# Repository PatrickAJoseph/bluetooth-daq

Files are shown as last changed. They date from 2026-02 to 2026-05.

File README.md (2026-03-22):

# bluetooth-daq
A simple low-speed Bluetooth enabled DAQ consisting of HV/LV voltage, current measurement, LV analog I/O, resistance measurement, UART, I2C & SPI communication interfaces and a high speed ADC combining multiple functionalities within one device. The device can be operated through a mobile/PC application via Bluetooth or through RS-485 interface. 16 devices can be connected to the RS-485 interface.

## Goal of the product
1. Reduce the number of induvidual electronic test equipment required for electronic hardware/software development.

2. Combine commonly used electronic test functions within a single device

3. Enable versatile interface to the device (RS485, Bluetooth, Web) and test automation support to reduce effort of manual testing.

## Features of the product

### Hardware features

1. 16 low-speed logic level digital inputs (+/ 3.3V) (maximum sampling rate of 100 SPS)
2. 16 low-speed logic level digital outputs (0-3V) with maximum current limit of 5mA / channel (maximum sampling rate of 100 SPS).
3. 2 channel bi-polar differential high-resolution analog inputs (+/-, 50V, 6 digits) with maximum sampling rate of 2 kSPS/channel in single channel sampling mode.
4. 2 channel high speed bipolar differential analog acquisition channels (maximum input signal frequency of 10kHz)
5. 1 UART communication instance (UART_TX, UART_RX) with maximum baud rate of 115200.
6. 1 I2C communication instance (I2C_SDA, I2C_SCL) with maximum clock speed of 400 kHz.
7. 1 SPI communication instance (SPI_MOSI, SPI_MISO, SPI_nCS, SPI_SCLK) with maximum clock speed of 4 MHz.
8. 8 channel differental bi-polar low voltage analog inputs +/- 15V range.
9. 2 current measurement inputs (+/- 50V common mode voltage, and maximum current of 3A).
10. 2 resistance measurement inputs ( 1 ohm to 1 MOhm ).
11. 2 thermistor temperature measurement channels.
12. 8 low speed DC analog outputs.
13. RS-485 interface for remote control.

### Software features

1. RS-485 control of device through PC.
2. Bluetooth control of device from PC/Mobile application.
3. Firmware upgrade through Bluetooth using TI Simplelink Connect app.
4. Simple Web GUI interface for control of device.
5. Python scripting support for remote control of device from PC.
6. LabVIEW support for the device.

## Hardware block diagram

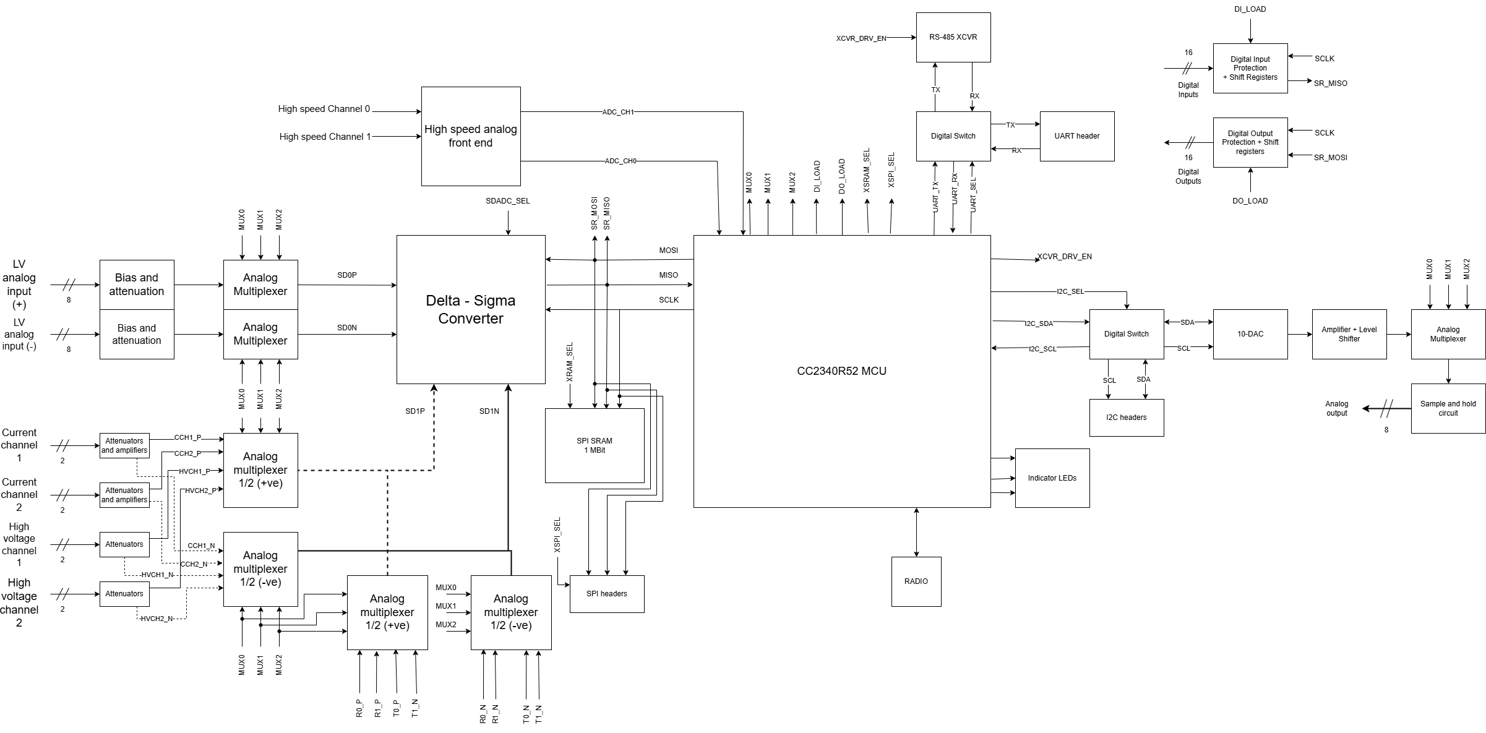
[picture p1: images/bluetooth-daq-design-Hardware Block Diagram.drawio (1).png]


### High voltage analog inputs

The device provides 2 high voltage analog inputs with a range of +/- 50V and maximum input frequency of 200 Hz. The high voltage analog input front end attenuates the input voltage signal and adds bias to meet voltage level requirements of the sigma-delta ADC inputs.

### Current inputs

The device provides 2 current inputs with common mode voltage upto +/- 50V and a range of +/- 3A. The voltage drop across the
current measurement terminal is 0.1V/A.

### Low voltage analog inputs

The device provides 8 channel +/- 15V low voltage analog inputs.
Maximum input frequency per channel is set to 200 Hz.

### Resistance measurement

The device provides 2 channel resistance measurement feature.
The supported resistance measurement range is 1 ohm to 1 MOhm.

### High speed acquisition channels

The device provides 2 single ended high speed analog signal
acquisition channels with sampling frequency of 200 kSPS per
channel, limiting the combined input signal frequency to 10kHz.

### Thermistor temperature measurement channels

The device provides 2 thermistor temperature measurement channels.
The reference voltage for the thermistor interface is 3.3V and reference resistance is 10k. The device comes with a calibration table for a 10K NTC. If user uses any other NTC, then, the calibration table for thermistor has to be manually entered by the user via software.

### Sigma-Delta ADC

The heart of most of the analog to digital conversions is carried out by a 24-bit sigma-delta ADC (ADS131M02: https://www.ti.com/lit/ds/symlink/ads131m02.pdf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).

The input to each channel of the ADC is multiplexed with the help of analog multiplexer (CD4051: https://www.ti.com/lit/ds/symlink/cd4051b.pdf)

### Low speed analog outputs

The device provides 8 analog outputs with range +/- 10V. Since a sample and hold circuit is used at the output stage, the output current limit is 1mA and so an external buffer must be used. The DAC used in the solution is DAC101C081 (https://www.ti.com/product/DAC101C081)

### SPI SRAM

The device uses a 1 MBit SRAM to store samples acquired from various modules such as high speed ADC, digital inputs, digital output patterns etc. The SRAM used is 23LCV1024 (https://ww1.microchip.com/downloads/en/DeviceDoc/25156A.pdf)

### Digital inputs and outputs

The device provides 16 digital inputs and digital outputs. The digital inputs are read by the MCU through a 74HC165 shift register (https://www.ti.com/lit/ds/symlink/sn74hc165.pdf) and the digital outputs are transferred through 74HC595 shift register (https://www.ti.com/lit/ds/symlink/sn74hc595.pdf).

The digital inputs have a range of +/- 3.3V in order to provided reverse voltage protection. The digital outputs have a current limit of 5mA per channel. 

### Indicator LEDs

There are three indicator LEDs, 1 green, 1 red and 1 yellow.
The green LED indicates status of any ongoing communication between host and the device. The red LED indicates any error which has occured in the device. The yello LED indicates that a firmware upgrade is going on the device.

### MCU

The microcontroller used in the device is CC2340R52 (https://www.ti.com/product/CC2340R5/part-details/CC2340R52E0RGER) which is an ARM Cortex-M0+ MCU with 512 KB FLASH and 36 KB RAM.

### UART, I2C and SPI interfaces

The device provides an SPI, I2C and a UART interface which can be used by the user to transfer bytes to external devices under test.

## Software block diagram

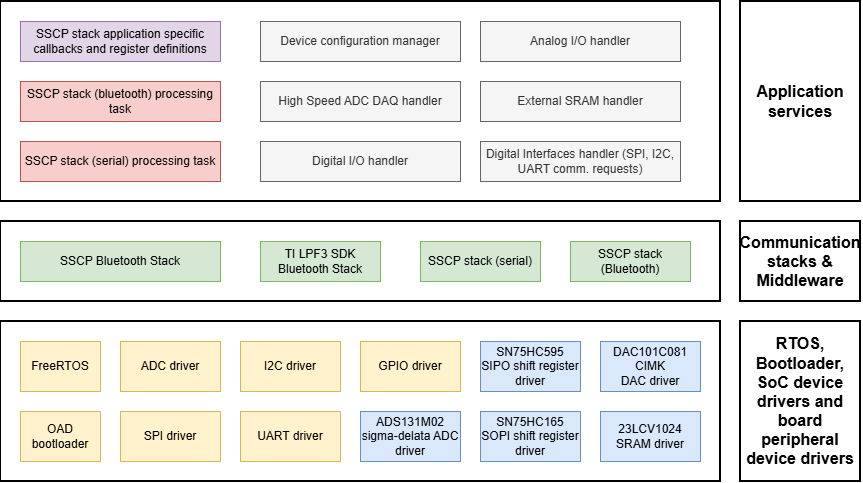
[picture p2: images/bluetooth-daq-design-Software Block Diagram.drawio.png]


### RTOS

The software uses FreeRTOS operating system. This is required by the TI Bluetooth Stack and also for multithreading purposes.

### Soc Peripheral Drivers

The following SoC peripheral drivers are required by the product.

| Driver | Description |
|---|---|
| ADC |  Required by the high speed analog input module  |
| SPI |  Required for accessing the shift registers <br> and the external SRAM memory |
| I2C |  Required to control DAC IC on the board |
| UART |  Required for interaction with host PC through RS-485 interface |
| GPIO | Required by all other drivers |

### Board Peripheral Drivers

| Driver | Purpose |
|---|---|
| ADS131M02 | Controls the 24-bit Sigma-Delta ADC. Performs common operations such as setting ADC PGA gain, calibration, sample acquisition etc. |
| SN75HC595 |  Write data to the digital outputs through shift registers |
| SN75HC165 |  Read data from the SOPI shift registers |
| DAC101C081 |  Required for controlling the external 10-bit for setting the desired output voltage. Also, supports calibration. |
| 23LCV1024 | Controls the external SRAM IC. Provides read and write APIs for the external memory |

### Bootloader and Firmware upgrade

The device supports over the air firmware upgrade through the TI Simplelink Connect application for Mobile (https://www.bing.com/search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). Firmware upgrade over Bluetooth is only supported for mobile phones and not for laptop.

### Bluetooth stack

The device uses the Texas Instruments Bluetooth stack. This stack is required for Bluetooth over the air firmware upgrade and also serves as an interface between the mobile/PC and the device.

### SSCP stack (serial) & SSCP stack (bluetooth)

The SSCP (Simple System Control Protocol) is the transport protocol which is used by the device to interact with the host via serial interface or Bluetooth. Each interface requires a seperate SSCP responder stack instance. For more details about the SSCP protocol refer to the following Git repository: https://github.com/PatrickAJoseph/simple-system-control-protocol.

### SSCP application interface

This software component defines the register callback functions, register definitions related to the application for the SSCP stack.

### SSCP responder stack processing task (serial & Bluetooth)

This software components receives bytes from the interface (serial/Bluetooth) and sends the received byets to the SSCP stack for processing.

### Device configuration manager

Validates the configuration provided by the user. Also, stores and loads device settings in non-volatile storage.

### High speed ADC data acquisition handler

Acquires samples from the high speed acquisition ADC channels and stores conversion results in the external SRAM. Users can then read back the samples stored in the SRAM.

### Digital I/O handler

Used to control the digital inputs and the digital outputs of the device through the shift registers as described in the hardware section. Supports setting, clearing, toggling each DO pin and reading state of DI pins.

### Analog I/O handler

Controls calibration of each high voltage analog input channel, current channel, resistance measurement channel, thermistor temperature measurement channel and analog output channel. Acquires samples from the analog input channels, performs filtering and then adds calibration parameters to provide processed results. Manages the multiplexing of different analog inputs to the input channels of the sigma-delta converter through the multiplexer.

### External SRAM handler

The external SRAM handler is an abstraction component for the external SRAM driver. Responsible for reading and writing data application defined memory regions in the external SRAM memory via the SPI interface.

### Digital interfaces handler (UART, SPI, I2C)

Used to handle received communication interface commands (such as transmit, receive commands) for UART, I2C and SPI protocols. Can handle multiple byte transfer for all interfaces and stores received bytes in the external SRAM for post processing.

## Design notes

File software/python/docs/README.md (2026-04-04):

# Python interface for bluetoth DAQ

The python interface for controlling the bluetooth data acquisition system consists of the following subcomponents:

**Core**: Contains the SSCP protocol core and helper methods to perform basic/common operations.

**Socket**: Implements a socket connection between the DAQ control python script and any other application such as LabVIEW, thereby making interfacing to various applications easier.

**DIO**: The **dio** submodule is used to control the digital inputs/outputs of the DAQ.

**UART**: The **uart** submodule is used to send bytes, receive bytes and transceive bytes via the UART interface of the DAQ.

**SPI**: The **spi** submodule is used to transceive bytes via the SPI inteface of the DAQ.

**I2C**: The **i2c** submodule is used to transceive bytes via the I2C interface of the DAQ.

**hv_analog_in**: The high voltage analog input submodule is used to measure the DC voltage at the high voltage analog inputs of the DAQ.

**lv_analog_in**: The low voltage analog input submodule is used to measure the DC voltage at the low voltage inputs of the DAQ.

**analog_out**: The analog output submodule is used to control the analog outputs of the DAQ.

**current**: The current submodule is used to measure the current flowing through the current measurement inputs of the DAQ.

**resistance**: The resistance submodule is used to measure the resistance across the resistance input terminals of the DAQ.

**temperature**: The temperature submodule is used to measure the resistance of the thermistor connected across the thermistor input terminals of the DAQ and map it to a temperature value based on the resistance-vs-temperature curve provided by the user.

## bdaq

The bluetooth DAQ API is the high level module which abstracts all other submodules. All other submodules are only accessible through this module. This module consists of functions to initialize the bluetooth DAQ, set the communication interface (Serial/BLE) and other utility functions.

### members

>__bdaq.interface__

Defines the type of communication interface used to communicate with the DAQ.

**Permitted values** 

__bdaq.interface.SERIAL__

Select communication interface as serial interface. Device will interact with the host PC via RS-485 interface.

__bdaq.interface.BLE__

Select communication interface as BLE interface. Device will interact with the host PC via BLE.

### methods

>**bdaq**( *interface*: **bdaq.interface**, *id*: **int**, *comm_timeout*: **int**, *serial_number*: **int**)

Initializes the SSCP protocol stack for communicating with the DAQ with the required interface, device ID, communication interface timeout and device serial number. It also puts the device into the default state.

***Parameters***

*interface* : The communcation interface between the DAQ and the host PC. Can be either BLE or SERIAL.

*id* : The device ID of the DAQ. This number is useful for addressing a specific device among a number of devices connected to the same RS485 bus. It can take an integer value from 0 to 15. Passing any other values throws an exception.

*comm_timeout* : The communication timeout period in milli-seconds. If the DAQ does not respond within the specified timeout, a timeout exception is thrown.

*serial_number* : A 10-digit serial number which will be associated a DAQ during production. This number is important when communicating with the device via BLE.

## Core

The **core** submodule abstracts the SSCP (https://github.com/PatrickAJoseph/simple-system-control-protocol/tree/main/source/python) protocol APIs. 

>**bdaq.core**( *interface*: **initiator.InterfaceType**, *id*: **int**, *comm_timeout*: **int**, *port* : **str**, *serial_number*: **int**)

Initializes the SSCP protocol stack for communicating with the DAQ with the required interface, device ID, communication interface timeout and device serial number.

***Parameters***

*interface* : The communcation interface between the DAQ and the host PC. Can be either BLE or SERIAL.

*id* : The device ID of the DAQ. This number is useful for addressing a specific device among a number of devices connected to the same RS485 bus. It can take an integer value from 0 to 15. Passing any other values throws an exception.

*comm_timeout* : The communication timeout period in milli-seconds. If the DAQ does not respond within the specified timeout, a timeout exception is thrown.

*port* : The port identifier of the COM Port / TTY used for serial communication.

*serial_number* : A 10-digit serial number which will be associated a DAQ during production. This number is important when communicating with the device via BLE.

>**bdaq.core.write_parameters**(*names*: **str[]**, *values*: **int[]**)

Writes the list of parameter names with the list of parameter values. This function takes longer time to execute as each parameter will be written to the device.

***Parameters***

*names* : The list of parameter names to be written into the device.

*values* : The list of corresponding parameter values to be written in the device.

>**bdaq.core.write_parameters_last**(*names*: **str[]**, *values*: **int[]**)

Writes the list of parameter names with the list of parameter values. This loads all parameter values into memory and only then initiates a write to device operation. __Make sure that all the parameters mentioned in the list belong to the same device register__ (Refer to `ble-daq.yml` configuration file for more details) 

***Parameters***

*names* : The list of parameter names to be written into the device.

*values* : The list of corresponding parameter values to be written in the device.

>**bdaq.core.read_parameters**(*names* : **str[]**)

Reads the list of parameters from the device and returns a list containing their values

***Parameters***

*names* : The list of parameter names to be read from the device.

## DIO

The **D**igital **I**nput **O**utput module is used to control the digital inputs and digital outputs of the DAQ. This module allows reading and writing states of all pins at once as well as individually.

>**daq.dio.read_input**()

Returns the states of the digital input pins as a 16-bit integer.

>**daq.dio.read_output**()

Returns the states of the digital output pins as a 16-bit integer.

>**daq.dio.write_output**(*output* : **int**)

Writes the 16-bit output word to the digital outputs of the DAQ.

*Parameters*

*output* : The 16-bit output which has to be written to the digital output pins of the DAQ. The value of *output* must range from 0 to 65535. Any other values throws a *ValueError*.

>**bdaq.dio.set_output_pin_state**( *pin* : **int**, *state* : **Bool** )

Sets state of digital output *pin* to the assigned *state*. The *pin* can take values from 0 to 15. Any other values throws *ValueError*.

*Parameters*

*pin* : The pin number of the digital output which has to be controlled. Valid value of *pin* is from 0 to 15.

*state* : The state of the digital output pin.

>**bdaq.dio.get_output_pin_state**( *pin* : **int** )

Gets the state of the output *pin*. Returns __True__ ifoutput state high, else, returns __False__

*Parameters*

*pin* : The pin number in the digital output whose state has to be examined.

>**bdaq.dio.toggle_output_pin_state**( *pin* : **int** )

Toggles the state of the output *pin*.

*Parameters*

*pin* : The pin number in the digital output whose state has to be toggled.

>**bdaq.dio.get_input_pin_state**( *pin* : **int** )

Gets the state of the digital input *pin*. Returns __True__ if input state is high, else, returns __False__

*Parameters*

*pin* : The pin number in the digital input whose state has to be examined.

## UART

The UART submodule provides features to configure the user UART, send data and receive data from an external device. The current implementation supports a data length of only 8 bits.

### Types

>**dio.uart.stop_bits**

Defines the number of supported stop bits. The device only supports 1 and 2 stop bits.

*dio.uart.stop_bits.ONE* : Number of stop bits is 1.

*dio.uart.stop_bits.TWO* : Number of stop bits is 2.

>**dio.uart.parity**

Defines the type of parity for a UART frame.

*dio.uart.parity.NONE* : Parity is set to none.

*dio.uart.parity.EVEN* : Parity is set to even.

*dio.uart.parity.ODD* : Parity is set to odd.

### Methods

>**bdaq.uart.configure**( *baud_rate* : **int**, *stop_bits* : **bdaq.uart.stop_bits**, *parity* : **bdaq.uart.parity** )

Configures the user UART with the specified baud rate, stop bits and parity.

*baud_rate* : The baud rate at which the UART bits have to be transferred. Valid baud rate is from 300 bps to 921600 bps. Values beyond this range will return error.

*stop_bits* : The number of stop bits. The stop bits must be mentioned via the enum.

*parity* : The parity bit settings. This argument must take one of the values from the __bdaq.uart.parity__ enum.

>**bdaq.uart.set_read_timeout**( *timeout* : **int** )

Sets the UART transfer timeout in milliseconds. Required for UART read operations. Timeout value can range from 0 to 60000. Values other than that will throw *ValueError*.

*timeout* : The UART read timeout specified in milli-seconds.

>**bdaq.uart.write**( *data* : **bytearray** )

Sends the bytes in *data* over the UART interface.

*data* : The data bytes to be sent over the UART TX line.

>**bdaq.uart.read**( *size* : **int**, *timeout* : **int** )

Reads the specified number of bytes (i.e.) *size* available in the UART RX line within the mentioned *timeout* period.

*size* : The number of bytes to be read from the UART RX line.

*timeout* : The timeout duration for the read operation along the UART RX line ( in __milliseconds__ )

>**bdaq.uart.read_then_write**( *write_data* : **bytearray**, *read_size* : **int**, *read_timeout* : **int** )

Reads the number of bytes from the UART Rx line within the mentioned timeout duration and when writes the specified bytes to the UART Tx line.

*write_data* : Byte array containing the btyes to be written via the UART Tx line.

*read_size* : The number of bytes to be read from the UART Rx line.

*read_timeout* : The timeout duration for the read operation along the UART Rx line ( in __milliseconds__ ).

>**bdaq.uart.write_then_read**( *write_data* : **bytearray**, *read_size* : **int**, *read_timeout* : **int** )

Writes the mentioned bytes along the UART Tx line and reads the bytes available along the UART Rx line within the specified timeout interval.

*write_data* : Byte array containing the btyes to be written via the UART Tx line.

*read_size* : The number of bytes to be read from the UART Rx line.

*read_timeout* : The timeout duration for the read operation along the UART Rx line ( in __milliseconds__ ).

## SPI

The SPI submodules provides features to configure the SPI controller and transfer bytes. The SPI module only supports MSB first transfers. LSB first transfers are not supported.

### Types

>**bdaq.spi.frame_format**

The SPI transfer frame format.

*bdaq.spi.frame_format.CPOL_0_CPHA_0* : SPI mode 0, Clock polarity is 0 and Clock phase is 0.

*bdaq.spi.frame_format.CPOL_0_CPHA_1* : SPI mode 0, Clock polarity is 0 and Clock phase is 1.

*bdaq.spi.frame_format.CPOL_1_CPHA_0* : SPI mode 0, Clock polarity is 1 and Clock phase is 0.

*bdaq.spi.frame_format.CPOL_1_CPHA_1* : SPI mode 0, Clock polarity is 1 and Clock phase is 1.

### Methods

>**bdaq.spi.configure**( *bit_rate* : **int**, *frame_format* : **bdaq.spi.frame_format** )

*bit_rate* : The frequency at which the data bits have to be trandferred. The *bit_rate* must a multiple of 10k and can range from 100kbps to 2 Mbps. Any other values results in *ValueError*.

*frame_format* : The frame format must take one of the values from __bsaq.spi.frame_format* enum.

>**bdaq.spi.transfer**( *write_data* : **bytearray** )

Sends over the bytes specified in the *write_data* byte array via the MOSI line and returns the read bytes via the MISO line in __bytearray__ format.

## I2C

The I2C submodule supports the I2C read and write operations to an I2C peripheral and configuration of the I2C peripheral. The supported modes are standard and fast mode and 7-bit addressing mode.

### Types

>**bdaq.i2c.mode**

Indicates whether transfer mode is standard or fast mode.

*bdaq.i2c.mode.standard* : Transfers bits at 100 kHz.

*bdaq.i2c.mode.fast* : Transfers bits at 400 kHz.

### Methods

>**bdaq.i2c.configure**( *mode* : **bdaq.i2c.mode**, *address* : **int** )

Configures the I2C controller with the required transfer mode and the target peripheral address.

*Parameters*

*mode* : The transfer mode must take arguments only from the bdaq.i2c.mode enum.

*address* : The supported target addresses are from 0 to 127. Passing any other value returns in a *ValueError*.

>**bdaq.i2c.transfer**( *write_data* : **bytearray**, *read_size* : **int** )

Sends over the bytes specified in the *write_data* byte array via the SDA line and reads *read_size* number of bytes from the peripheral via the SDA line.

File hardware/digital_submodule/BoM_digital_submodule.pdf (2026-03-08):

Component label | Component value | Component name
U1, U2 | | SN74HC595D
U3, U4 | | SN74HC165D
U7, U8 | | CD4053BM
U5 | | 23LCV1024
U6 | | SN75176ADR
R1,R2,R3,R4,R5,R6,R7,R8,R9,R10,R 11,R12,R13,R14,R15,R16,R17,R18, R19,R20,R21,R22,R23,R24,R25,R26 ,R27,R28,R29,R30,R31,R32,R33,R3 4,R35 | 620E, 1/4W | SMD resistor
R200, R26, R17, R41, R42, R43, R57, R27, R49 | 10k, 1/4W | SMD resistor
R48, R51, R53, R55 | 22E, 1/4W | SMD resistor
D36, D37, D38, D39, D35, D34, D33 | | SMAJ5.0CA
R39, R40 | 1k, 1/4W | SMD resistor
R38 | 120E, 1/4W | SMD resistor
R58, R59 | 2.2k, 1/4W | SMD resistor
C1,C2,C3,C4,C5,C6,C7,C8,C9,C10,C 11,C12,C13,C14,C15,C16,C29,C30, C31,C32,C33,C34,C35,C36,C40,C41 ,C42,C43,C44,C45,C46,C47 | 100pF, 50V, ceramic | SMD capacitor
DIP0, DIP1, DIP2, DIP3, DIP4, DIP5,DIP6, DIP7, DIP8, DIP9, DIP10, DIP11, DIP12, DIP13, DIP14, DIP15 | 1A, 40V, SS14, Schottky diode | SS14 / Schottky Diode
C48, C17, C23, C20, C51, C54, C56, C37 | 100nF, 50v, ceramic | SMD capacitor
C49, C18, C24, C21, C52, C55, C57, C36 | 1u, 50V, ceramic | SMD capacitor
C50, C19, C25, C22, C53, C39 | 10u, 50V, ceramic | SMD capacitor

Quantity | Footprint / package / size
4 | SOIC(D) 16
4 | SOIC(D) 16
4 | SOIC(D) 16
2 | SOIC-8
2 | SOIC-8
40 | SMD_0805
20 | SMD_0805
10 | SMD_0805
20 | DO_214AC
10 | SMD_0805
5 | SMD_1206
10 | SMD_0805
40 | SMD_0805
30 | DO_214AC
20 | SMD_0805
20 | SMD_0805
20 | SMD_0805

Purchase link

SN74HC595D Texas Instruments | Integrated Circuits (ICs) | DigiKey (https://www.digikey.com/en/products/detail/texas-instruments/SN74HC595D/376752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)
SN74HC165D Texas Instruments | Integrated Circuits (ICs) | DigiKey
Marketplace (https://www.digikey.com/en/products/detail/texas-instruments/SN74HC165D/376951)
CD4053BM Texas Instruments | Integrated Circuits (ICs) | DigiKey
Marketplace (https://www.digikey.com/en/products/detail/texas-instruments/CD4053BM/1691172)
23LCV1024-I/SN Microchip Technology | Integrated Circuits (ICs) |
DigiKey (https://www.digikey.com/en/products/detail/microchip-technology/23LCV1024-I-SN/3543093)
SN75176ADR Texas Instruments | Integrated Circuits (ICs) | DigiKey (https://www.digikey.in/en/products/detail/texas-instruments/SN75176ADR/562956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)
RC0805JR-07620RL YAGEO | Resistors | DigiKey (https://www.digikey.in/en/products/detail/yageo/RC0805JR-07620RL/728357)
CRCW080510K0JNEA Vishay Dale | Resistors | DigiKey (https://www.digikey.com/en/products/detail/vishay-dale/CRCW080510K0JNEA/1175222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)
CR0805-JW-220ELF Bourns Inc. | Resistors | DigiKey (https://www.digikey.in/en/products/detail/bourns-inc/CR0805-JW-220ELF/3785269)
SMAJ5.0CA Shenzhen Slkormicro Semicon Co., Ltd. | Circuit
Protection | DigiKey (https://www.digikey.in/en/products/detail/shenzhen-slkormicro-semicon-co-ltd/SMAJ5-0CA/25701316)
Generic
Generic
Generic

Generic

SS14 onsemi | Discrete Semiconductor Products | DigiKey (https://www.digikey.com/en/products/detail/onsemi/SS14/965474?msockid=05dadbf74f856ea33b13cf394e376f90)

Generic

Generic
Generic

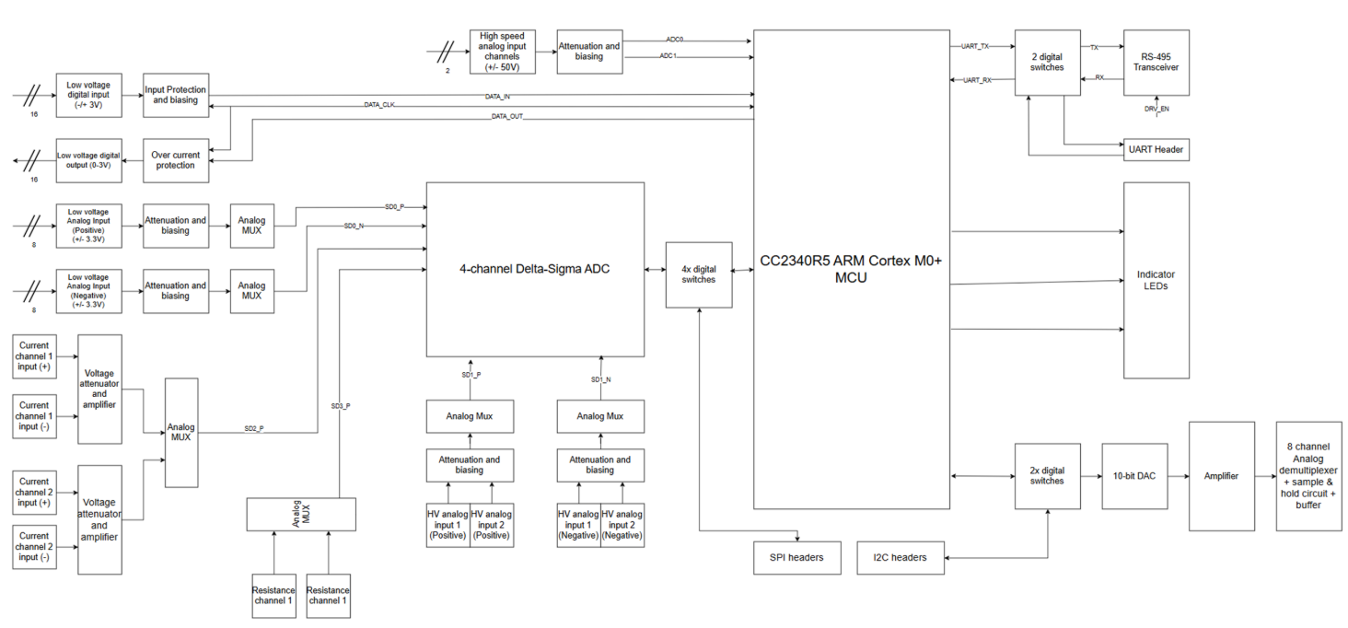
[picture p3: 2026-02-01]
image.png

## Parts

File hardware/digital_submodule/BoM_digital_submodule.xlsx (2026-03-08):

Component label | Component value | Component name | Quantity | Footprint / package / size | Purchase link
U1, U2 |  | SN74HC595D | 4 | SOIC(D) 16 | SN74HC595D Texas Instruments | Integrated Circuits (ICs) | DigiKey (https://www.digikey.com/en/products/detail/texas-instruments/SN74HC595D/376752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)
U3, U4 |  | SN74HC165D | 4 | SOIC(D) 16 | SN74HC165D Texas Instruments | Integrated Circuits (ICs) | DigiKey Marketplace (https://www.digikey.com/en/products/detail/texas-instruments/SN74HC165D/376951)
U7, U8 |  | CD4053BM | 4 | SOIC(D) 16 | CD4053BM Texas Instruments | Integrated Circuits (ICs) | DigiKey Marketplace (https://www.digikey.com/en/products/detail/texas-instruments/CD4053BM/1691172)
U5 |  | 23LCV1024 | 2 | SOIC-8 | 23LCV1024-I/SN Microchip Technology | Integrated Circuits (ICs) | DigiKey (https://www.digikey.com/en/products/detail/microchip-technology/23LCV1024-I-SN/3543093)
U6 |  | SN75176ADR | 2 | SOIC-8 | SN75176ADR Texas Instruments | Integrated Circuits (ICs) | DigiKey (https://www.digikey.in/en/products/detail/texas-instruments/SN75176ADR/562956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)
R1,R2,R3,R4,R5,R6,R7,R8,R9,R10,R11,R12,R13,R14,R15,R16,R17,R18,R19,R20,R21,R22,R23,R24,R25,R26,R27,R28,R29,R30,R31,R32,R33,R34,R35 | 620E, 1/4W | SMD resistor | 40 | SMD_0805 | RC0805JR-07620RL YAGEO | Resistors | DigiKey (https://www.digikey.in/en/products/detail/yageo/RC0805JR-07620RL/728357)
R200, R26, R17, R41, R42, R43, R57, R27, R49 | 10k, 1/4W | SMD resistor | 20 | SMD_0805 | CRCW080510K0JNEA Vishay Dale | Resistors | DigiKey (https://www.digikey.com/en/products/detail/vishay-dale/CRCW080510K0JNEA/1175222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)
R48, R51, R53, R55 | 22E, 1/4W | SMD resistor | 10 | SMD_0805 | CR0805-JW-220ELF Bourns Inc. | Resistors | DigiKey (https://www.digikey.in/en/products/detail/bourns-inc/CR0805-JW-220ELF/3785269)
D36, D37, D38, D39, D35, D34, D33 |  | SMAJ5.0CA | 20 | DO_214AC | SMAJ5.0CA Shenzhen Slkormicro Semicon Co., Ltd. | Circuit Protection | DigiKey (https://www.digikey.in/en/products/detail/shenzhen-slkormicro-semicon-co-ltd/SMAJ5-0CA/25701316)
R39, R40 | 1k, 1/4W | SMD resistor | 10 | SMD_0805 | Generic
R38 | 120E, 1/4W | SMD resistor | 5 | SMD_1206 | Generic
R58, R59 | 2.2k, 1/4W | SMD resistor | 10 | SMD_0805 | Generic
C1,C2,C3,C4,C5,C6,C7,C8,C9,C10,C11,C12,C13,C14,C15,C16,C29,C30,C31,C32,C33,C34,C35,C36,C40,C41,C42,C43,C44,C45,C46,C47 | 100pF, 50V, ceramic | SMD capacitor | 40 | SMD_0805 | Generic
DIP0, DIP1, DIP2, DIP3, DIP4, DIP5,DIP6, DIP7, DIP8, DIP9, DIP10, DIP11, DIP12, DIP13, DIP14, DIP15 | 1A, 40V, SS14, Schottky diode | SS14 / Schottky Diode | 30 | DO_214AC | SS14 onsemi | Discrete Semiconductor Products | DigiKey (https://www.digikey.com/en/products/detail/onsemi/SS14/965474?msockid=05dadbf74f856ea33b13cf394e376f90)
C48, C17, C23, C20, C51, C54, C56, C37 | 100nF, 50v, ceramic | SMD capacitor | 20 | SMD_0805 | Generic
C49, C18, C24, C21, C52, C55, C57, C36 | 1u, 50V, ceramic | SMD capacitor | 20 | SMD_0805 | Generic
C50, C19, C25, C22, C53, C39 | 10u, 50V, ceramic | SMD capacitor | 20 | SMD_0805 | Generic

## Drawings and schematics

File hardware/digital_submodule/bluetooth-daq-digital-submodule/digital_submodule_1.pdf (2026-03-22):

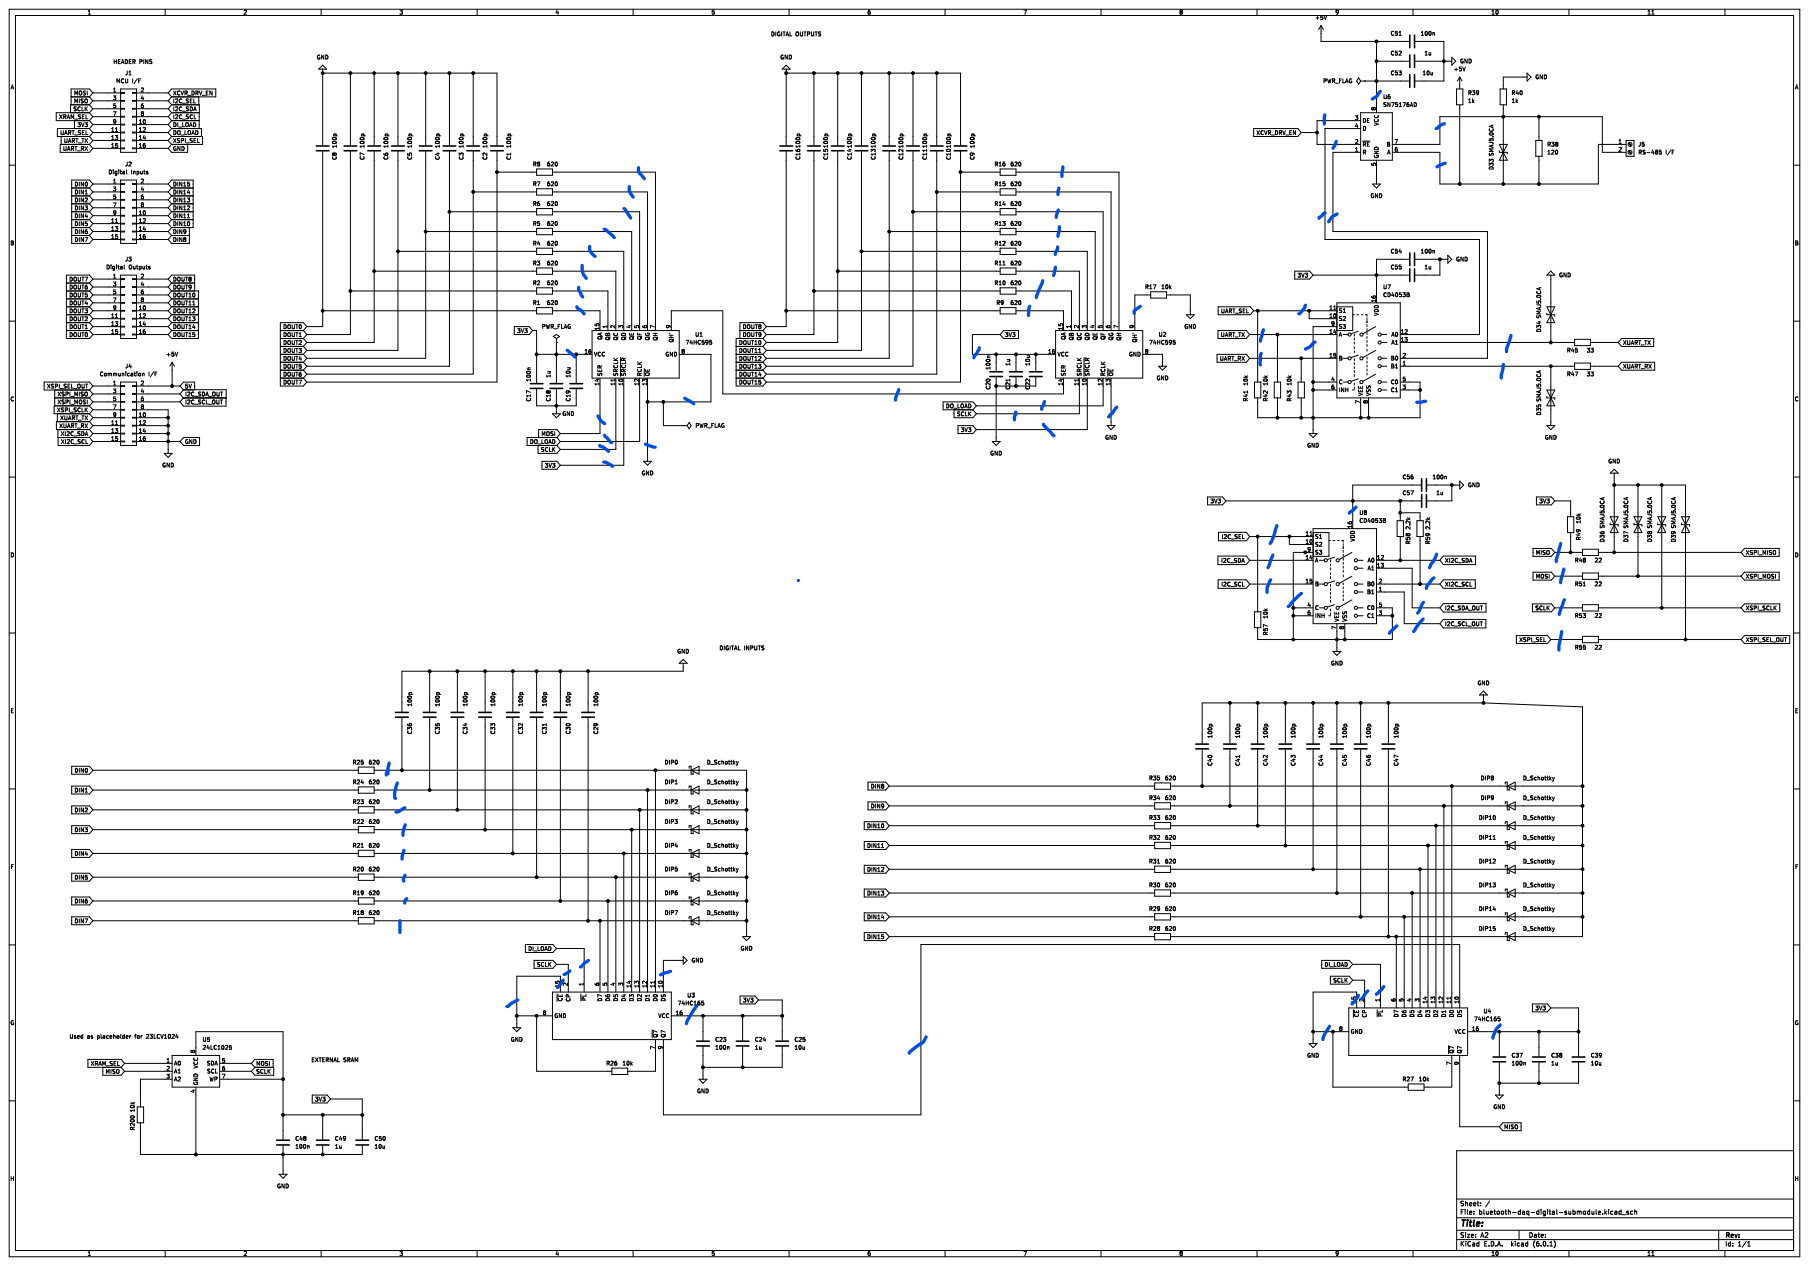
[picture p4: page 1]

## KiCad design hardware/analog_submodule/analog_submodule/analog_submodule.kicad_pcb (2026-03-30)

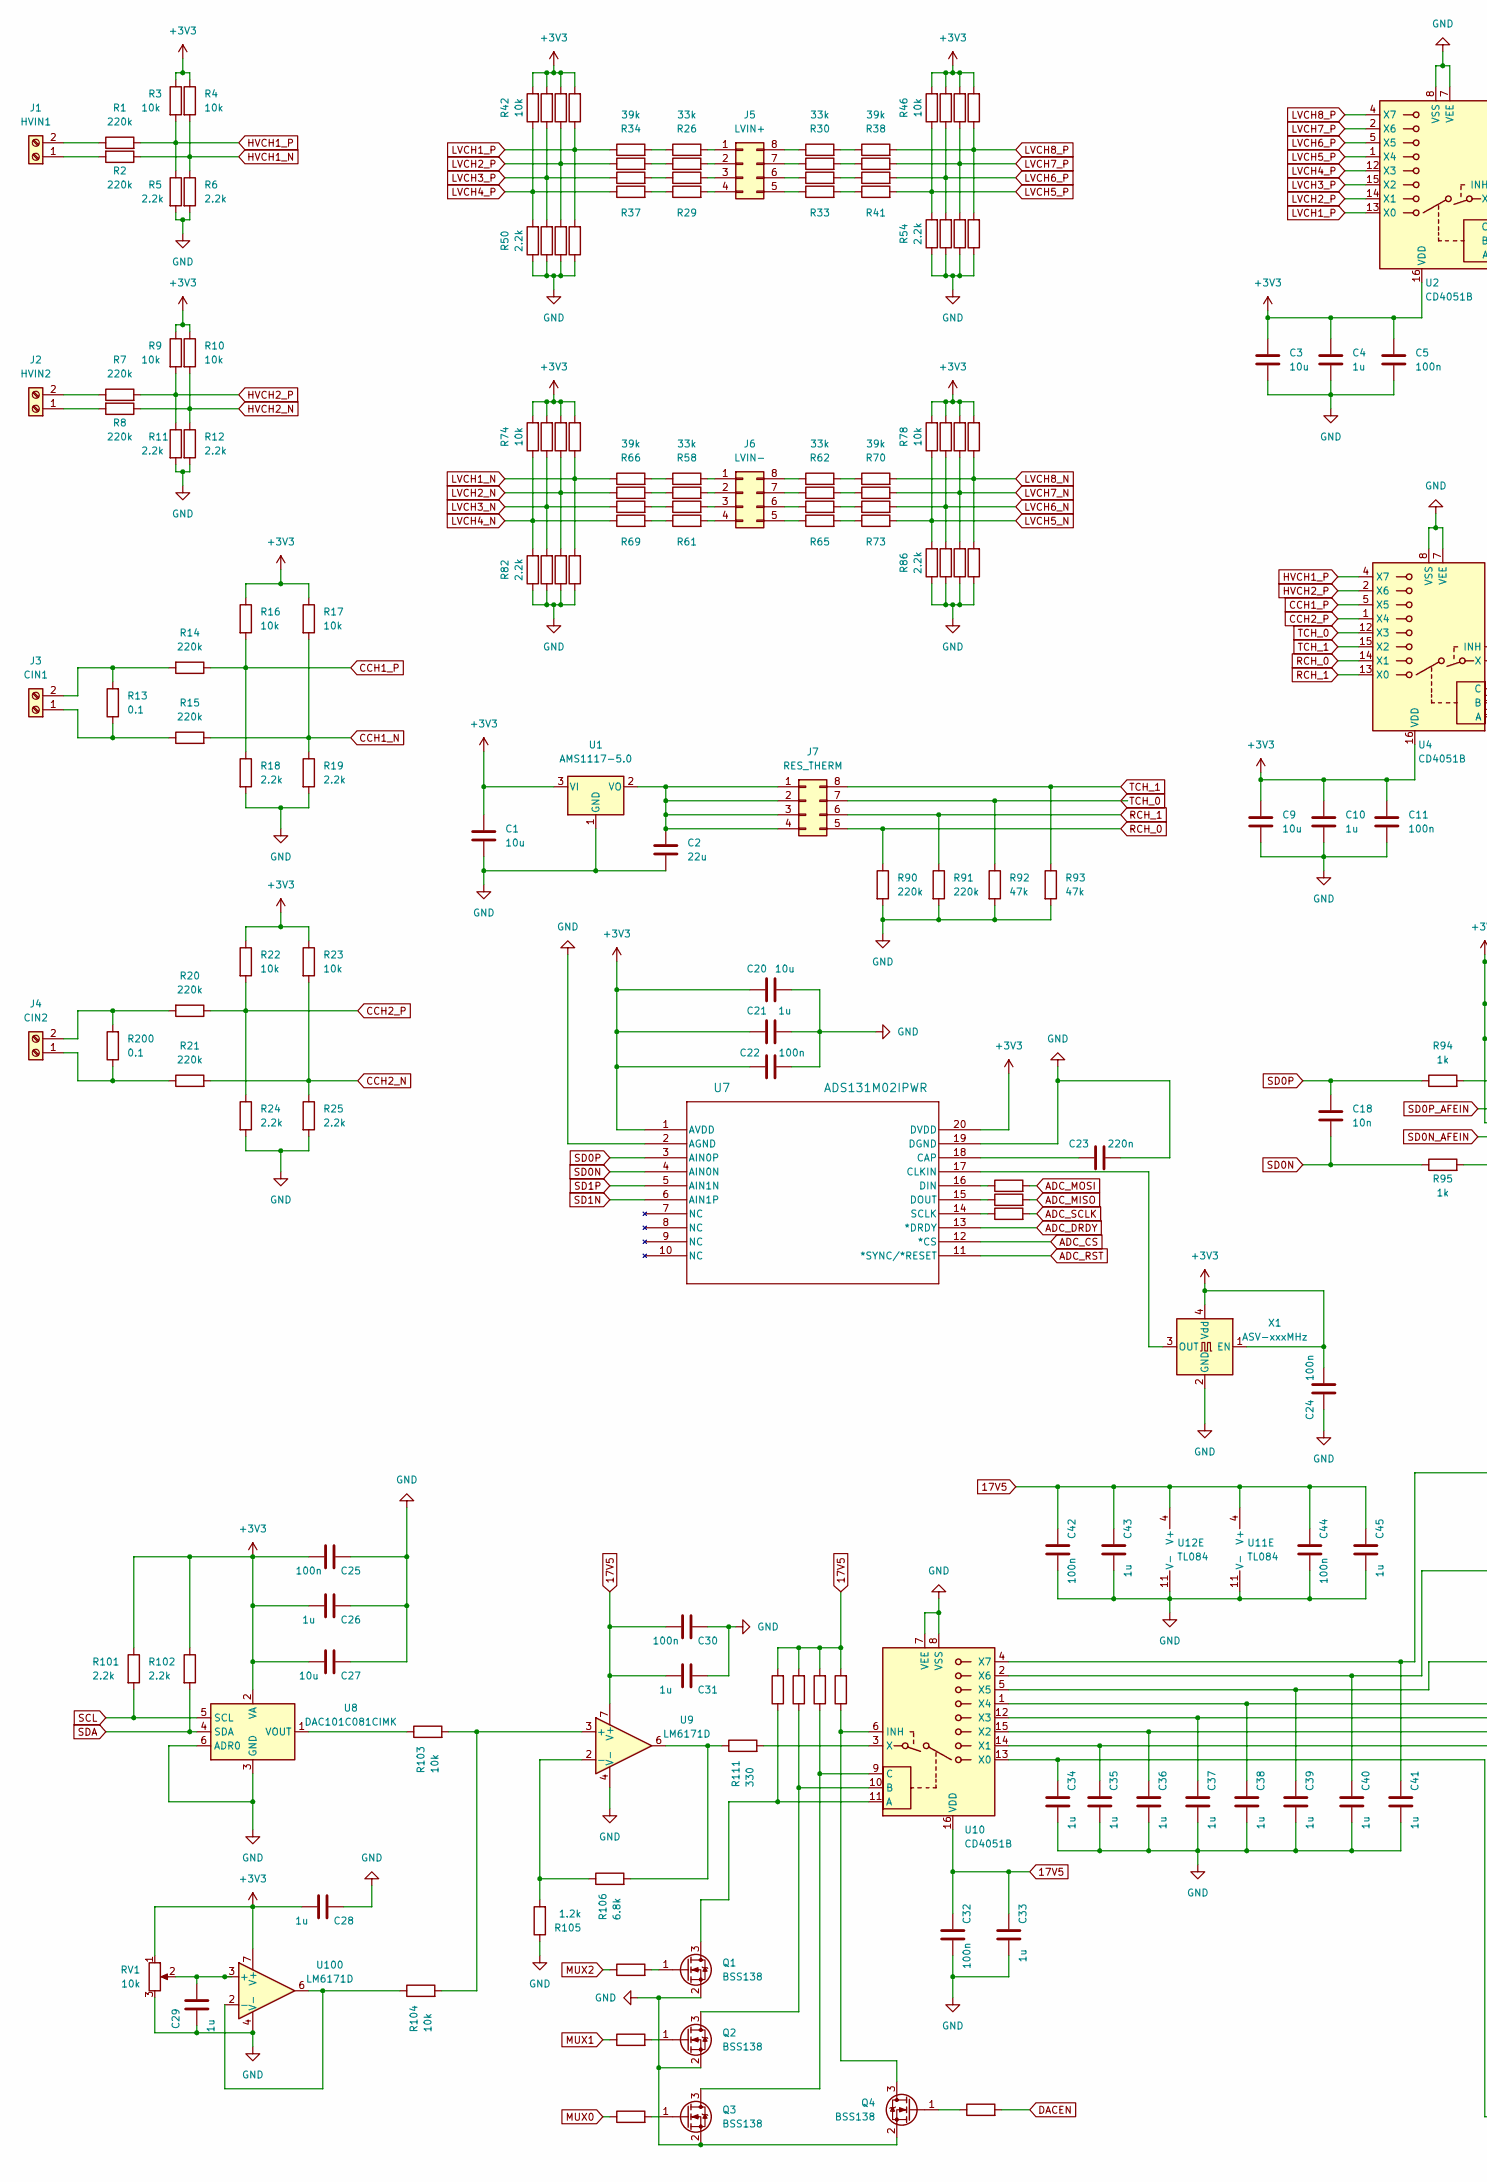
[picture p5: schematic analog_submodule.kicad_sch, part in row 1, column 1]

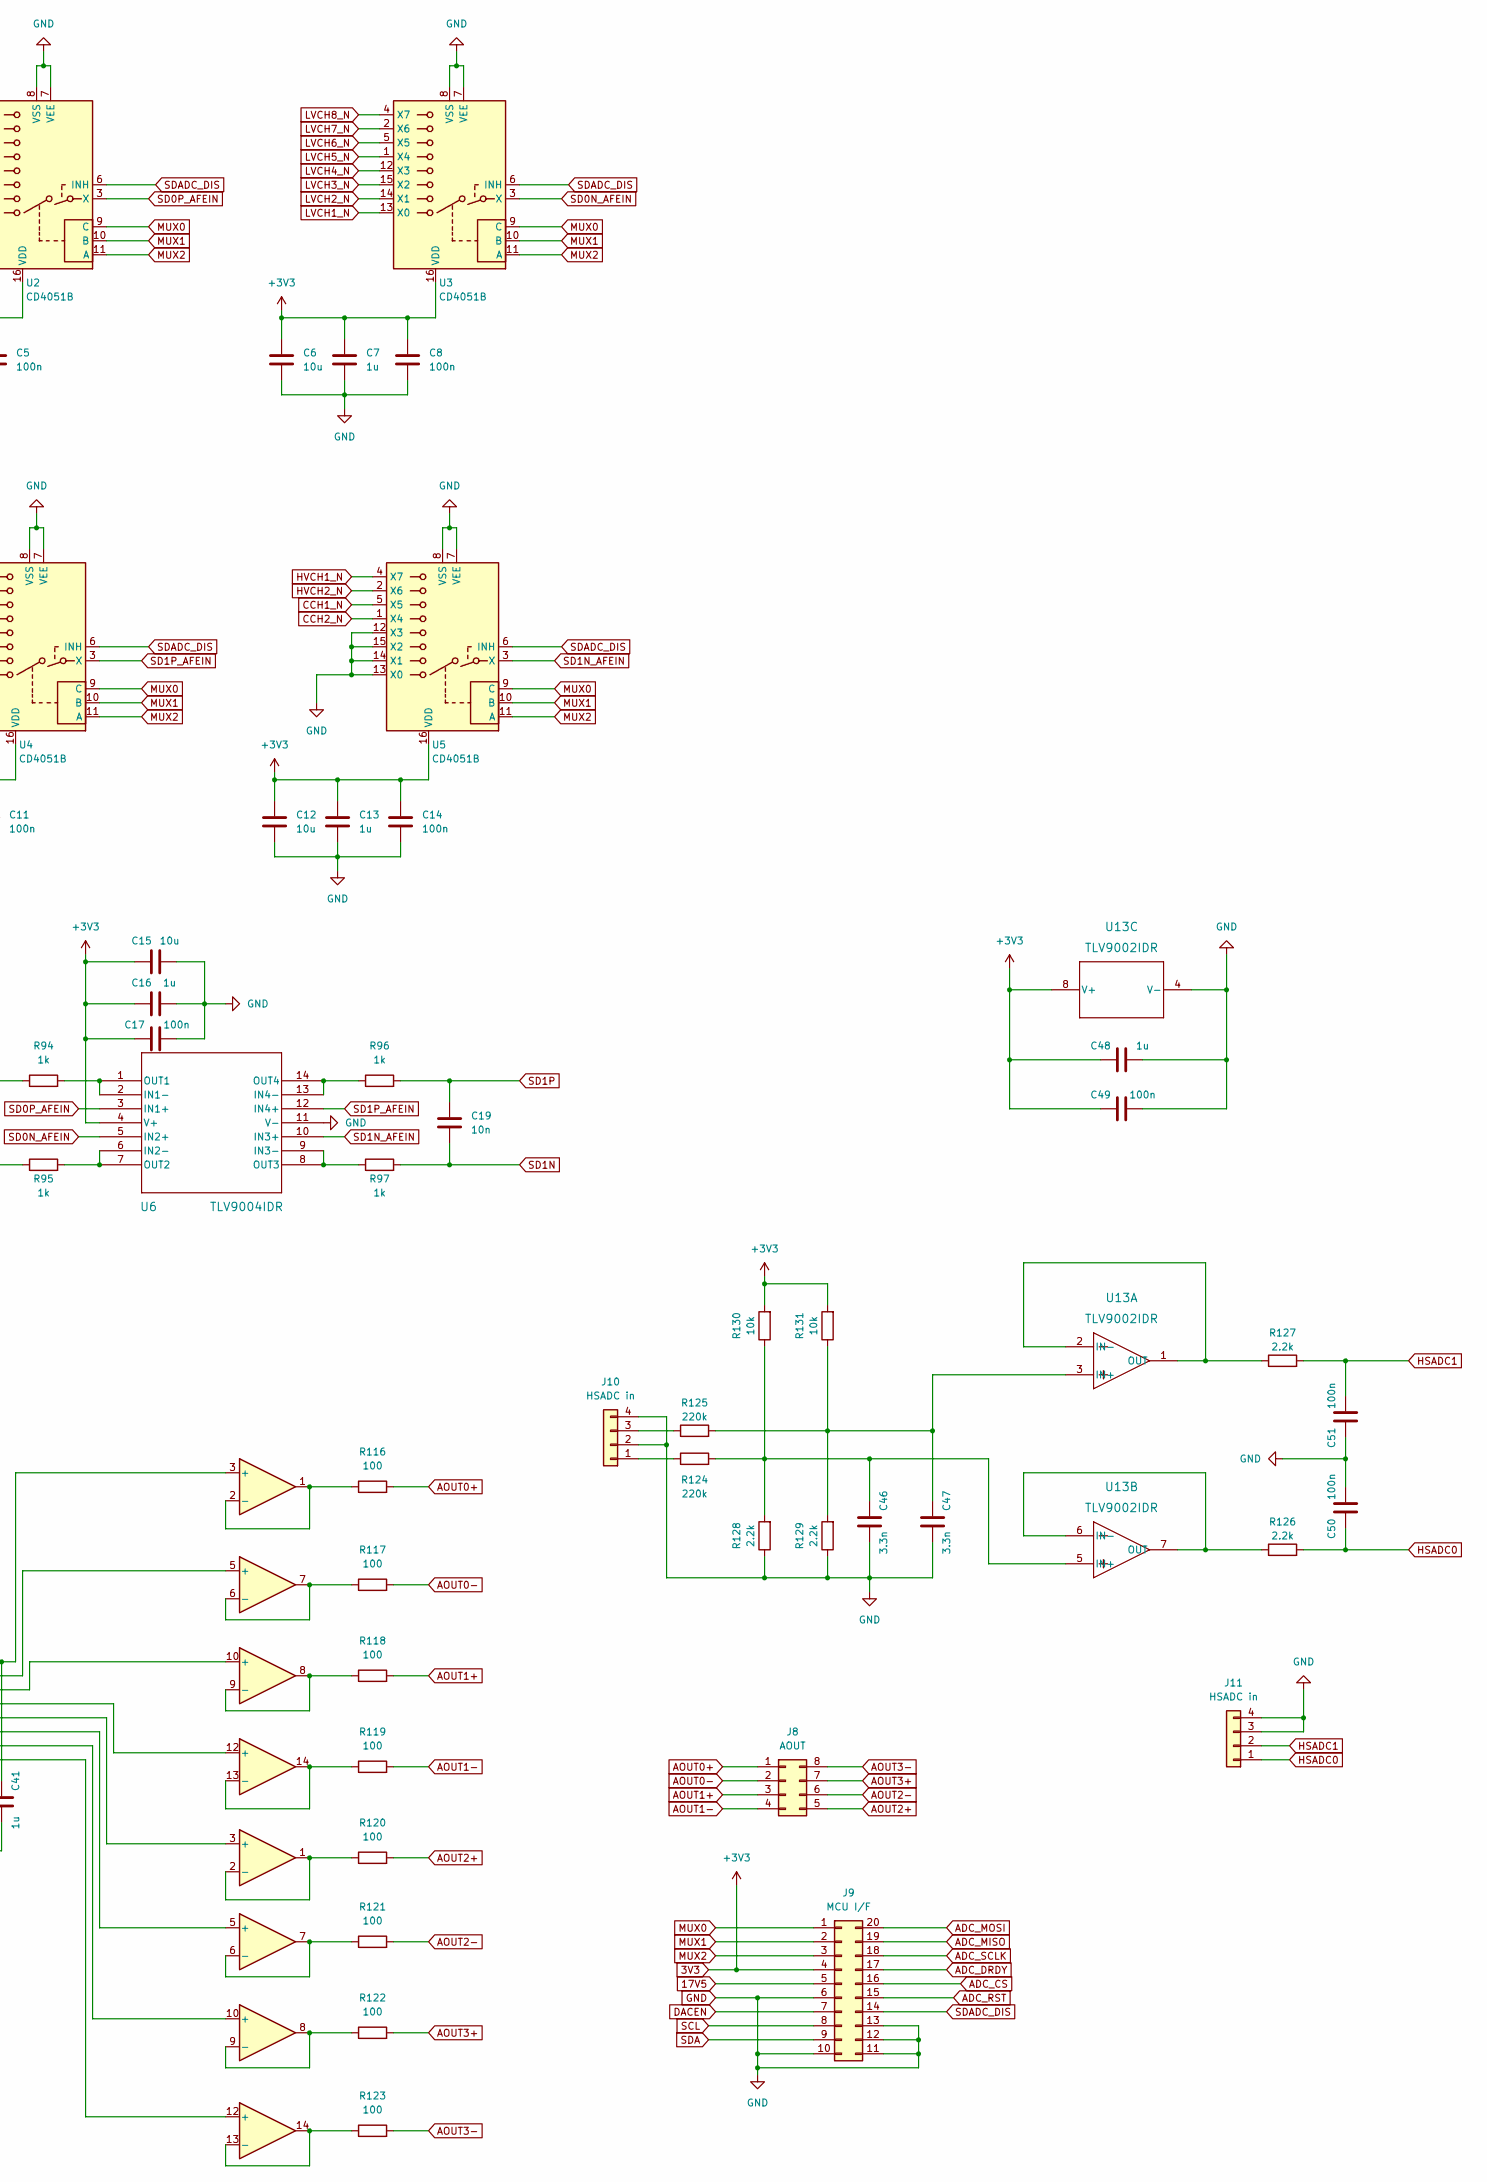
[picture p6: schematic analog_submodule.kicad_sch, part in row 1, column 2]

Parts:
C1, C3, C6, C9, C12, C15, C20, C27: 10u; C_0805_2012Metric_Pad1.18x1.45mm_HandSolder
C2: 22u; C_0805_2012Metric_Pad1.18x1.45mm_HandSolder
C4, C7, C10, C13, C16, C21, C26, C28, C29, C31, C33, C34, C35, C36, C37, C38, C39, C40, C41, C43, C45, C48: 1u; C_0805_2012Metric_Pad1.18x1.45mm_HandSolder
C5, C8, C11, C14, C17, C22, C24, C25, C30, C32, C42, C44, C49, C50, C51: 100n; C_0805_2012Metric_Pad1.18x1.45mm_HandSolder
C18, C19: 10n; C_0805_2012Metric_Pad1.18x1.45mm_HandSolder
C23: 220n; C_0805_2012Metric_Pad1.18x1.45mm_HandSolder
C46, C47: 3.3n; C_0805_2012Metric_Pad1.18x1.45mm_HandSolder
J1: HVIN1; PhoenixContact_MCV_1,5_2-G-5.08_1x02_P5.08mm_Vertical
J2: HVIN2; PhoenixContact_MCV_1,5_2-G-5.08_1x02_P5.08mm_Vertical
J3: CIN1; PhoenixContact_MCV_1,5_2-G-5.08_1x02_P5.08mm_Vertical
J4: CIN2; PhoenixContact_MCV_1,5_2-G-5.08_1x02_P5.08mm_Vertical
J5: LVIN+; PinHeader_2x04_P2.54mm_Vertical
J6: LVIN-; PinHeader_2x04_P2.54mm_Vertical
J7: RES_THERM; PinHeader_2x04_P2.54mm_Vertical
J8: AOUT; PinHeader_2x04_P2.54mm_Vertical
J9: MCU I/F; PinHeader_2x10_P2.54mm_Vertical
J10, J11: HSADC in; PinHeader_1x04_P2.54mm_Vertical
Q1, Q2, Q3, Q4: BSS138; SOT-23
R1, R2, R7, R8, R14, R15, R20, R21, R90, R91, R124, R125: 220k; R_0805_2012Metric_Pad1.20x1.40mm_HandSolder
R3, R4, R9, R10, R16, R17, R22, R23, R42, R43, R44, R45, R46, R47, R48, R49, R74, R75, R76, R77, R78, R79, R80, R81, R103, R104, R107, R108, R109, R110, R130, R131: 10k; R_0805_2012Metric_Pad1.20x1.40mm_HandSolder
R5, R6, R11, R12, R18, R19, R24, R25, R50, R51, R52, R53, R54, R55, R56, R57, R82, R83, R84, R85, R86, R87, R88, R89, R101, R102, R126, R127, R128, R129: 2.2k; R_0805_2012Metric_Pad1.20x1.40mm_HandSolder
R13, R200: 0.1; R_2512_6332Metric_Pad1.40x3.35mm_HandSolder
R26, R27, R28, R29, R30, R31, R32, R33, R58, R59, R60, R61, R62, R63, R64, R65: 33k; R_0805_2012Metric_Pad1.20x1.40mm_HandSolder
R34, R35, R36, R37, R38, R39, R40, R41, R66, R67, R68, R69, R70, R71, R72, R73: 39k; R_0805_2012Metric_Pad1.20x1.40mm_HandSolder
R92, R93: 47k; R_0805_2012Metric_Pad1.20x1.40mm_HandSolder
R94, R95, R96, R97, R112, R113, R114, R115: 1k; R_0805_2012Metric_Pad1.20x1.40mm_HandSolder
R98, R99, R100: 22; R_0805_2012Metric_Pad1.20x1.40mm_HandSolder
R105: 1.2k; R_0805_2012Metric_Pad1.20x1.40mm_HandSolder
R106: 6.8k; R_0805_2012Metric_Pad1.20x1.40mm_HandSolder
R111: 330; R_0805_2012Metric_Pad1.20x1.40mm_HandSolder
R116, R117, R118, R119, R120, R121, R122, R123: 100; R_0805_2012Metric_Pad1.20x1.40mm_HandSolder
RV1: 10k; Potentiometer_Bourns_3266Y_Vertical
U1: AMS1117-5.0; SOT-223-3_TabPin2
U2, U3, U4, U5, U10: CD4051B; D16
U6: TLV9004IDR; SOIC-14_3.9x8.7mm_P1.27mm
U7: ADS131M02IPWR; TSSOP-20_4.4x6.5mm_P0.65mm
U8: DAC101C081CIMK; SOT-23-6
U9, U100: LM6171D; SOIC-8_3.9x4.9mm_P1.27mm
U11, U12: TL084; SOIC-14_3.9x8.7mm_P1.27mm
U13: TLV9002IDR; SOIC-8_3.9x4.9mm_P1.27mm
X1: ASV-xxxMHz; Oscillator_SMD_Abracon_ASV-4Pin_7.0x5.1mm

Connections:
3V3: C1.1, C3.1, C4.1, C5.1, C6.1, C7.1, C8.1, C9.1, C10.1, C11.1, C12.1, C13.1, C14.1, C15.1, C16.1, C17.1, C20.1, C21.1, C22.1, C24.2, C25.2, C26.2, C27.2, C28.2, C48.1, C49.1, J9.4, R3.1, R4.1, R9.1, R10.1, R16.1, R17.1, R22.1, R23.1, R42.2, R43.2, R44.2, R45.2, R46.2, R47.2, R48.2, R49.2, R74.2, R75.2, R76.2, R77.2, R78.2, R79.2, R80.2, R81.2, R101.1, R102.1, R130.2, R131.2, RV1.1, U1.3 (VI), U2.16 (VDD), U3.16 (VDD), U4.16 (VDD), U5.16 (VDD), U6.4 (V+), U7.1 (AVDD), U7.20 (DVDD), U8.2 (VA), U13.8 (V+), U100.7 (V+), X1.1 (EN), X1.4 (Vdd)
17V5: C30.2, C31.2, C32.1, C33.1, C42.1, C43.1, C44.1, C45.1, J9.5, R107.2, R108.2, R109.2, R110.2, U9.7 (V+), U10.16 (VDD), U11.4 (V+), U12.4 (V+)
ADC_CS: J9.16, U7.12 (*CS)
ADC_DRDY: J9.17, U7.13 (*DRDY)
ADC_MISO: J9.19, R99.2
ADC_MOSI: J9.20, R98.2
ADC_RST: J9.15, U7.11 (*SYNC/*RESET)
ADC_SCLK: J9.18, R100.2
AOUT0+: J8.1, R116.2
AOUT0-: J8.2, R117.2
AOUT1+: J8.3, R118.2
AOUT1-: J8.4, R119.2
AOUT2+: J8.5, R120.2
AOUT2-: J8.6, R121.2
AOUT3+: J8.7, R122.2
AOUT3-: J8.8, R123.2
CCH1_N: R15.2, R17.2, R19.1, U5.5 (X5)
CCH1_P: R14.1, R16.2, R18.1, U4.5 (X5)
CCH2_N: R21.2, R23.2, R25.1, U5.1 (X4)
CCH2_P: R20.1, R22.2, R24.1, U4.1 (X4)
DACEN: J9.7, R115.2
GND: C1.2, C2.2, C3.2, C4.2, C5.2, C6.2, C7.2, C8.2, C9.2, C10.2, C11.2, C12.2, C13.2, C14.2, C15.2, C16.2, C17.2, C20.2, C21.2, C22.2, C23.2, C24.1, C25.1, C26.1, C27.1, C28.1, C29.2, C30.1, C31.1, C32.2, C33.2, C34.2, C35.2, C36.2, C37.2, C38.2, C39.2, C40.2, C41.2, C42.2, C43.2, C44.2, C45.2, C46.2, C47.2, C48.2, C49.2, C50.2, C51.1, J9.6, J9.10, J9.11, J9.12, J9.13, J10.2, J10.4, J11.3, J11.4, Q1.2 (S), Q2.2 (S), Q3.2 (S), Q4.2 (S), R5.2, R6.2, R11.2, R12.2, R18.2, R19.2, R24.2, R25.2, R50.1, R51.1, R52.1, R53.1, R54.1, R55.1, R56.1, R57.1, R82.1, R83.1, R84.1, R85.1, R86.1, R87.1, R88.1, R89.1, R90.2, R91.2, R92.2, R93.2, R105.1, R128.1, R129.1, RV1.3, U1.1 (GND), U2.7 (VEE), U2.8 (VSS), U3.7 (VEE), U3.8 (VSS), U4.7 (VEE), U4.8 (VSS), U5.7 (VEE), U5.8 (VSS), U5.12 (X3), U5.13 (X0), U5.14 (X1), U5.15 (X2), U6.11 (V-), U7.2 (AGND), U7.19 (DGND), U8.3 (GND), U8.6 (ADR0), U9.4 (V-), U10.7 (VEE), U10.8 (VSS), U11.11 (V-), U12.11 (V-), U13.4 (V-), U100.4 (V-), X1.2 (GND)
HSADC0: C50.1, J11.1, R126.2
HSADC1: C51.2, J11.2, R127.2
HVCH1_N: R2.1, R4.2, R6.1, U5.4 (X7)
HVCH1_P: R1.2, R3.2, R5.1, U4.4 (X7)
HVCH2_N: R8.1, R10.2, R12.1, U5.2 (X6)
HVCH2_P: R7.2, R9.2, R11.1, U4.2 (X6)
LVCH1_N: R66.1, R77.1, R85.2, U3.13 (X0)
LVCH1_P: R34.1, R45.1, R53.2, U2.13 (X0)
LVCH2_N: R67.1, R76.1, R84.2, U3.14 (X1)
LVCH2_P: R35.1, R44.1, R52.2, U2.14 (X1)
LVCH3_N: R68.1, R75.1, R83.2, U3.15 (X2)
LVCH3_P: R36.1, R43.1, R51.2, U2.15 (X2)
LVCH4_N: R69.1, R74.1, R82.2, U3.12 (X3)
LVCH4_P: R37.1, R42.1, R50.2, U2.12 (X3)
LVCH5_N: R73.2, R78.1, R86.2, U3.1 (X4)
LVCH5_P: R41.2, R46.1, R54.2, U2.1 (X4)
LVCH6_N: R72.2, R79.1, R87.2, U3.5 (X5)
LVCH6_P: R40.2, R47.1, R55.2, U2.5 (X5)
LVCH7_N: R71.2, R80.1, R88.2, U3.2 (X6)
LVCH7_P: R39.2, R48.1, R56.2, U2.2 (X6)
LVCH8_N: R70.2, R81.1, R89.2, U3.4 (X7)
LVCH8_P: R38.2, R49.1, R57.2, U2.4 (X7)
MUX0: J9.1, R114.1, U2.9 (C), U3.9 (C), U4.9 (C), U5.9 (C)
MUX1: J9.2, R113.1, U2.10 (B), U3.10 (B), U4.10 (B), U5.10 (B)
MUX2: J9.3, R112.1, U2.11 (A), U3.11 (A), U4.11 (A), U5.11 (A)
unnamed: C2.1, J7.1, J7.2, J7.3, J7.4, U1.2 (VO)
unnamed: C23.1, U7.18 (CAP)
unnamed: C29.1, RV1.2, U100.3 (+)
unnamed: C34.1, U10.13 (X0), U12.12 (+)
unnamed: C35.1, U10.14 (X1), U12.10 (+)
unnamed: C36.1, U10.15 (X2), U12.5 (+)
unnamed: C37.1, U10.12 (X3), U12.3 (+)
unnamed: C38.1, U10.1 (X4), U11.12 (+)
unnamed: C39.1, U10.5 (X5), U11.10 (+)
unnamed: C40.1, U10.2 (X6), U11.5 (+)
unnamed: C41.1, U10.4 (X7), U11.3 (+)
unnamed: C46.1, R124.2, R128.2, R130.1, U13.5 (IN+)
unnamed: C47.1, R125.2, R129.2, R131.1, U13.3 (IN+)
unnamed: J1.1, R2.2
unnamed: J1.2, R1.1
unnamed: J2.1, R8.2
unnamed: J2.2, R7.1
unnamed: J3.1, R13.1, R15.1
unnamed: J3.2, R13.2, R14.2
unnamed: J4.1, R21.1, R200.1
unnamed: J4.2, R20.2, R200.2
unnamed: J5.1, R26.2
unnamed: J5.2, R27.2
unnamed: J5.3, R28.2
unnamed: J5.4, R29.2
unnamed: J5.5, R33.1
unnamed: J5.6, R32.1
unnamed: J5.7, R31.1
unnamed: J5.8, R30.1
unnamed: J6.1, R58.2
unnamed: J6.2, R59.2
unnamed: J6.3, R60.2
unnamed: J6.4, R61.2
unnamed: J6.5, R65.1
unnamed: J6.6, R64.1
unnamed: J6.7, R63.1
unnamed: J6.8, R62.1
unnamed: J10.1, R124.1
unnamed: J10.3, R125.1
unnamed: Q1.1 (G), R112.2
unnamed: Q1.3 (D), R107.1, U10.11 (A)
unnamed: Q2.1 (G), R113.2
unnamed: Q2.3 (D), R108.1, U10.10 (B)
unnamed: Q3.1 (G), R114.2
unnamed: Q3.3 (D), R109.1, U10.9 (C)
unnamed: Q4.1 (G), R115.1
unnamed: Q4.3 (D), R110.1, U10.6 (INH)
unnamed: R26.1, R34.2
unnamed: R27.1, R35.2
unnamed: R28.1, R36.2
unnamed: R29.1, R37.2
unnamed: R30.2, R38.1
unnamed: R31.2, R39.1
unnamed: R32.2, R40.1
unnamed: R33.2, R41.1
unnamed: R58.1, R66.2
unnamed: R59.1, R67.2
unnamed: R60.1, R68.2
unnamed: R61.1, R69.2
unnamed: R62.2, R70.1
unnamed: R63.2, R71.1
unnamed: R64.2, R72.1
unnamed: R65.2, R73.1
unnamed: R94.2, U6.1 (OUT1), U6.2 (IN1-)
unnamed: R95.2, U6.6 (IN2-), U6.7 (OUT2)
unnamed: R96.1, U6.13 (IN4-), U6.14 (OUT4)
unnamed: R97.1, U6.8 (OUT3), U6.9 (IN3-)
unnamed: R98.1, U7.16 (DIN)
unnamed: R99.1, U7.15 (DOUT)
unnamed: R100.1, U7.14 (SCLK)
unnamed: R103.1, U8.1 (VOUT)
unnamed: R103.2, R104.2, U9.3 (+)
unnamed: R104.1, U100.2 (-), U100.6
unnamed: R105.2, R106.1, U9.2 (-)
unnamed: R106.2, R111.1, U9.6
unnamed: R111.2, U10.3 (X)
unnamed: R116.1, U11.1, U11.2 (-)
unnamed: R117.1, U11.6 (-), U11.7
unnamed: R118.1, U11.8, U11.9 (-)
unnamed: R119.1, U11.13 (-), U11.14
unnamed: R120.1, U12.1, U12.2 (-)
unnamed: R121.1, U12.6 (-), U12.7
unnamed: R122.1, U12.8, U12.9 (-)
unnamed: R123.1, U12.13 (-), U12.14
unnamed: R126.1, U13.6 (IN-), U13.7 (OUT)
unnamed: R127.1, U13.1 (OUT), U13.2 (IN-)
unnamed: U7.17 (CLKIN), X1.3 (OUT)
RCH_0: J7.5, R90.1, U4.14 (X1)
RCH_1: J7.6, R91.1, U4.13 (X0)
SCL: J9.8, R101.2, U8.5 (SCL)
SD0N: C18.2, R95.1, U7.4 (AIN0N)
SD0N_AFEIN: U3.3 (X), U6.5 (IN2+)
SD0P: C18.1, R94.1, U7.3 (AIN0P)
SD0P_AFEIN: U2.3 (X), U6.3 (IN1+)
SD1N: C19.2, R97.2, U7.6 (AIN1P)
SD1N_AFEIN: U5.3 (X), U6.10 (IN3+)
SD1P: C19.1, R96.2, U7.5 (AIN1N)
SD1P_AFEIN: U4.3 (X), U6.12 (IN4+)
SDA: J9.9, R102.2, U8.4 (SDA)
SDADC_DIS: J9.14, U2.6 (INH), U3.6 (INH), U4.6 (INH), U5.6 (INH)
TCH_0: J7.7, R92.1, U4.12 (X3)
TCH_1: J7.8, R93.1, U4.15 (X2)

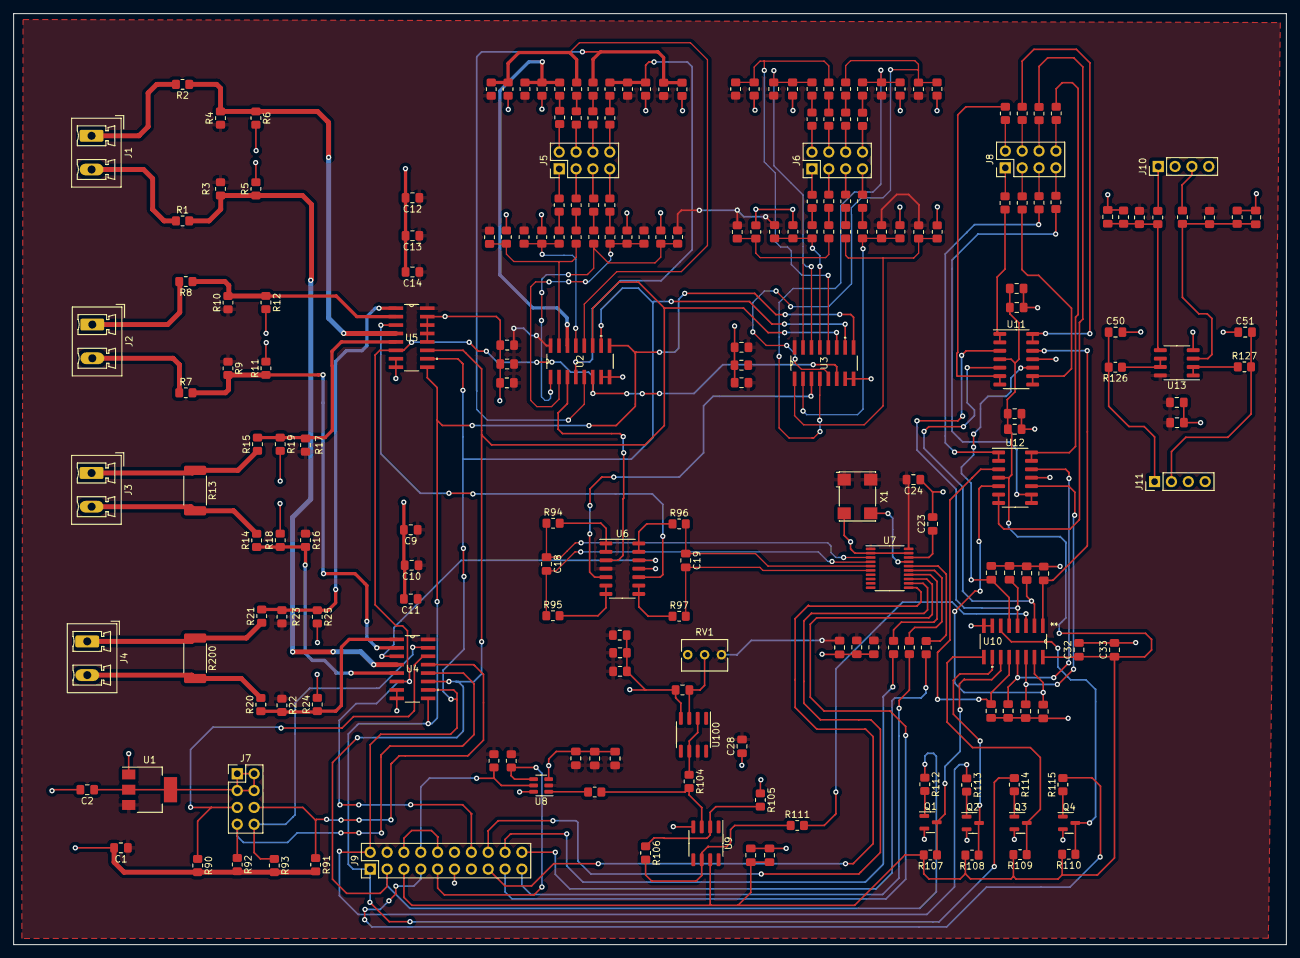
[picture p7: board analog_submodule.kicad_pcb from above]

Board: 2 copper layers, 191.8 x 140.3 mm, 214 parts (0 on the bottom side), 149 nets.

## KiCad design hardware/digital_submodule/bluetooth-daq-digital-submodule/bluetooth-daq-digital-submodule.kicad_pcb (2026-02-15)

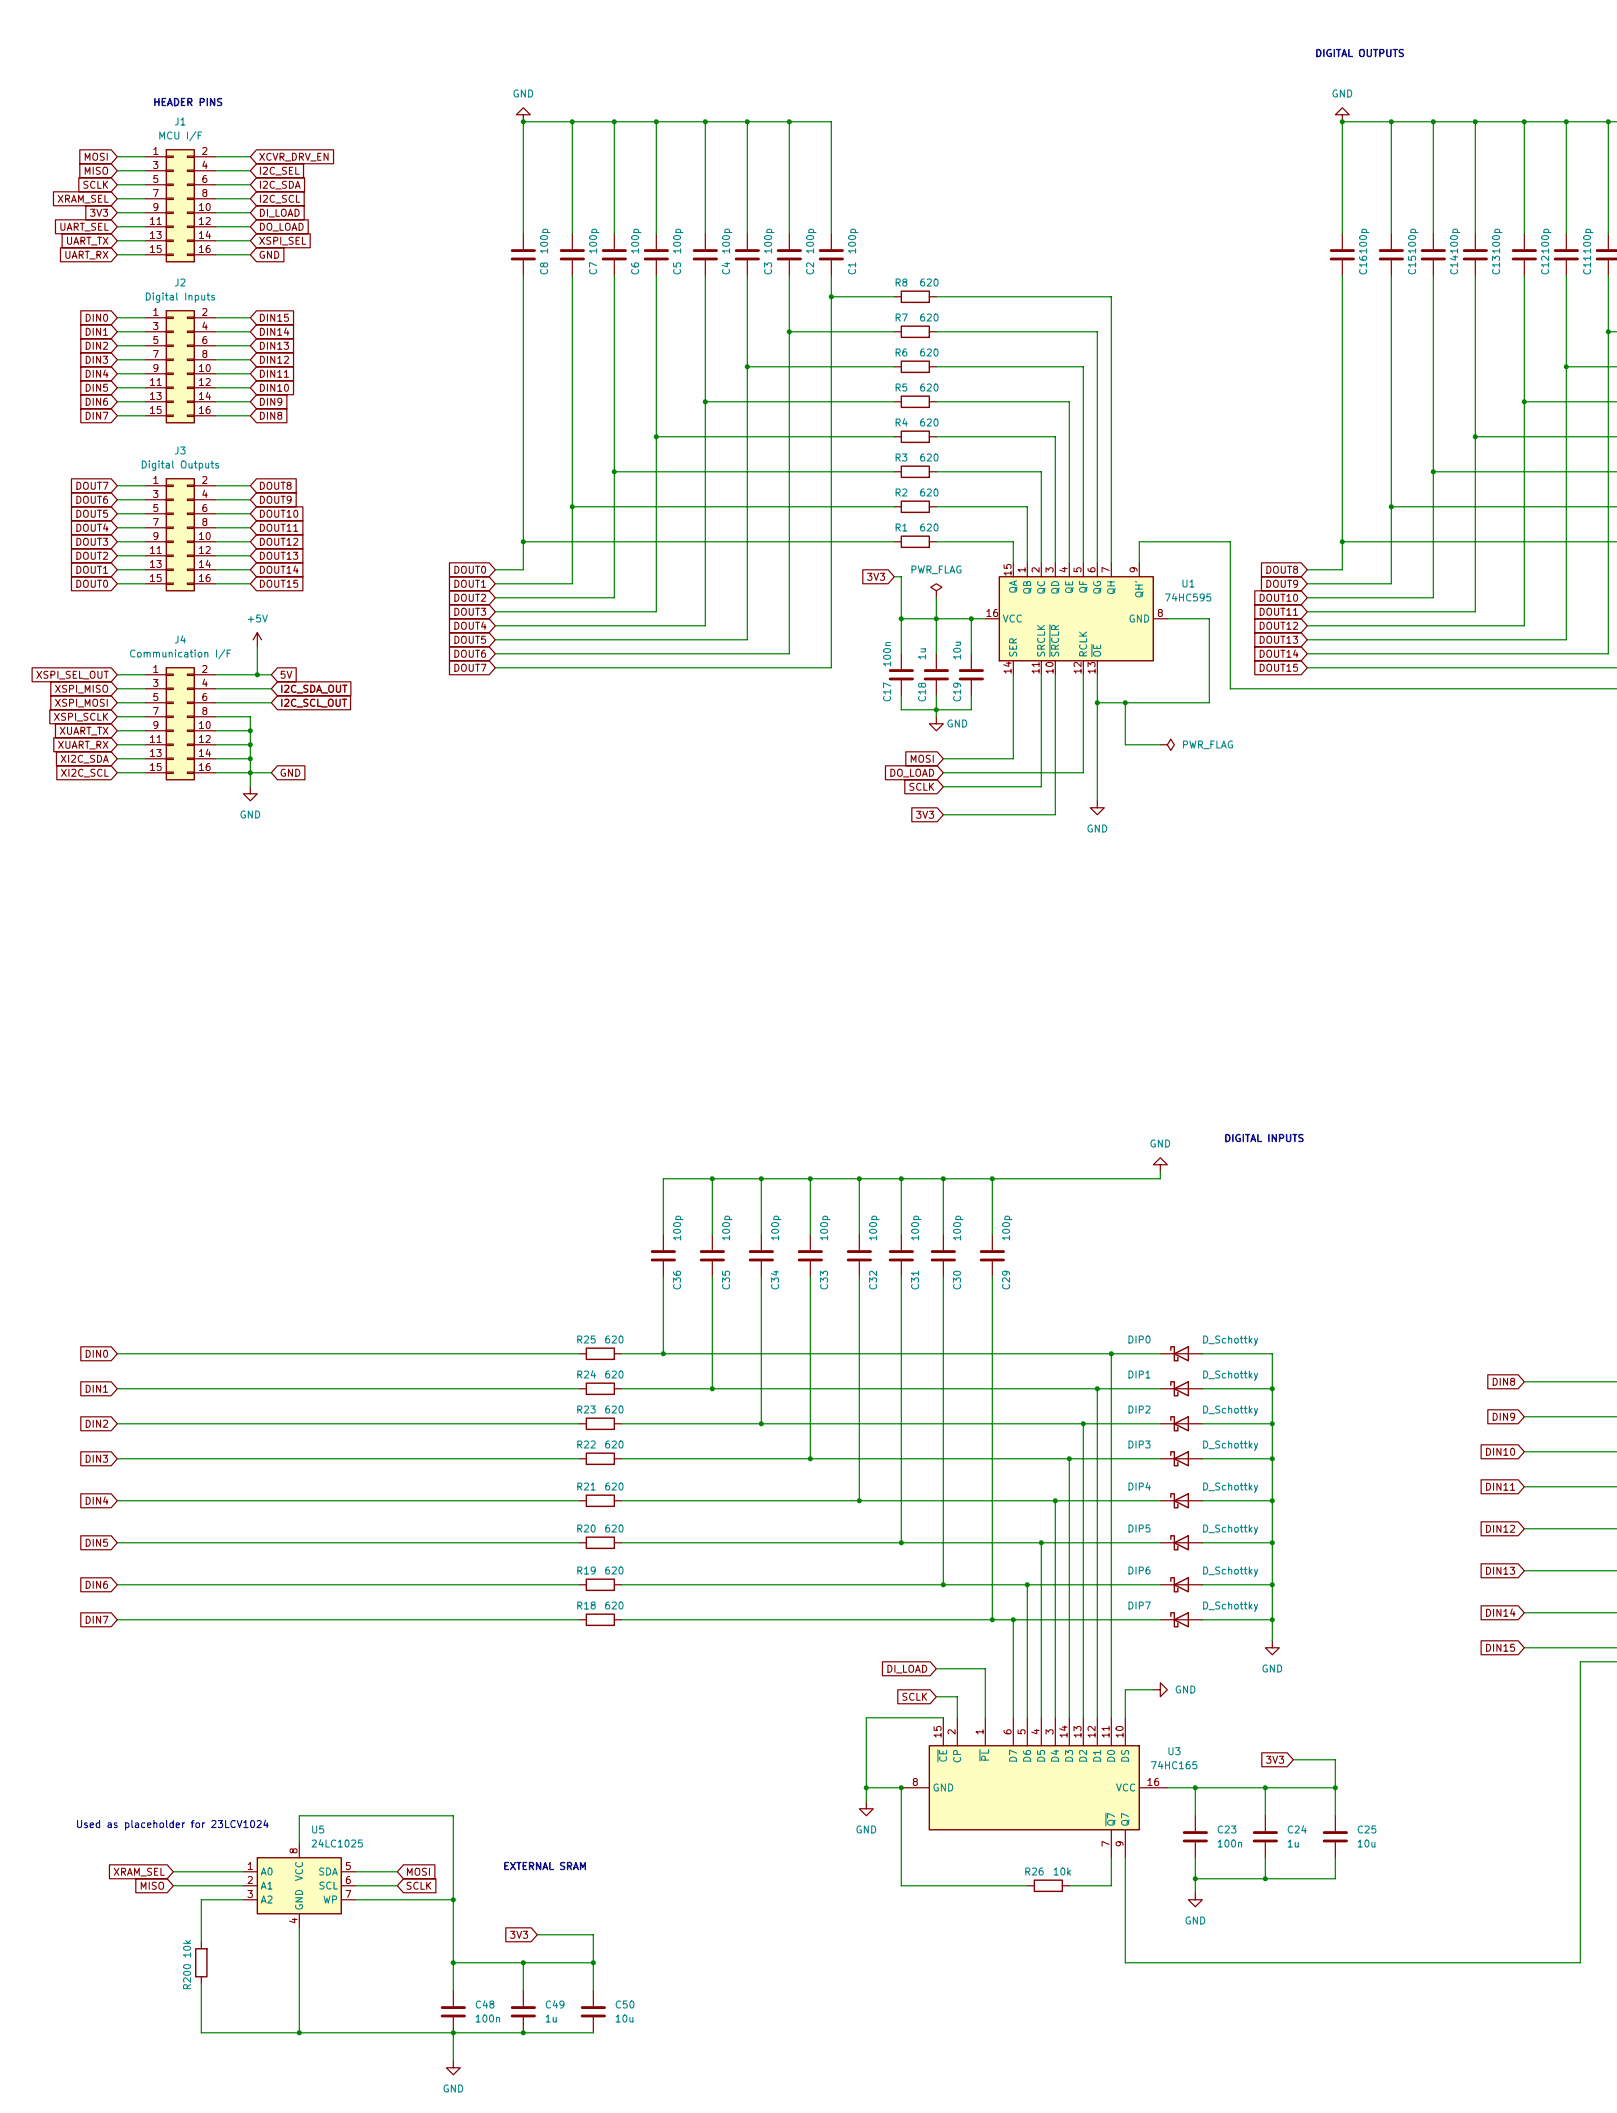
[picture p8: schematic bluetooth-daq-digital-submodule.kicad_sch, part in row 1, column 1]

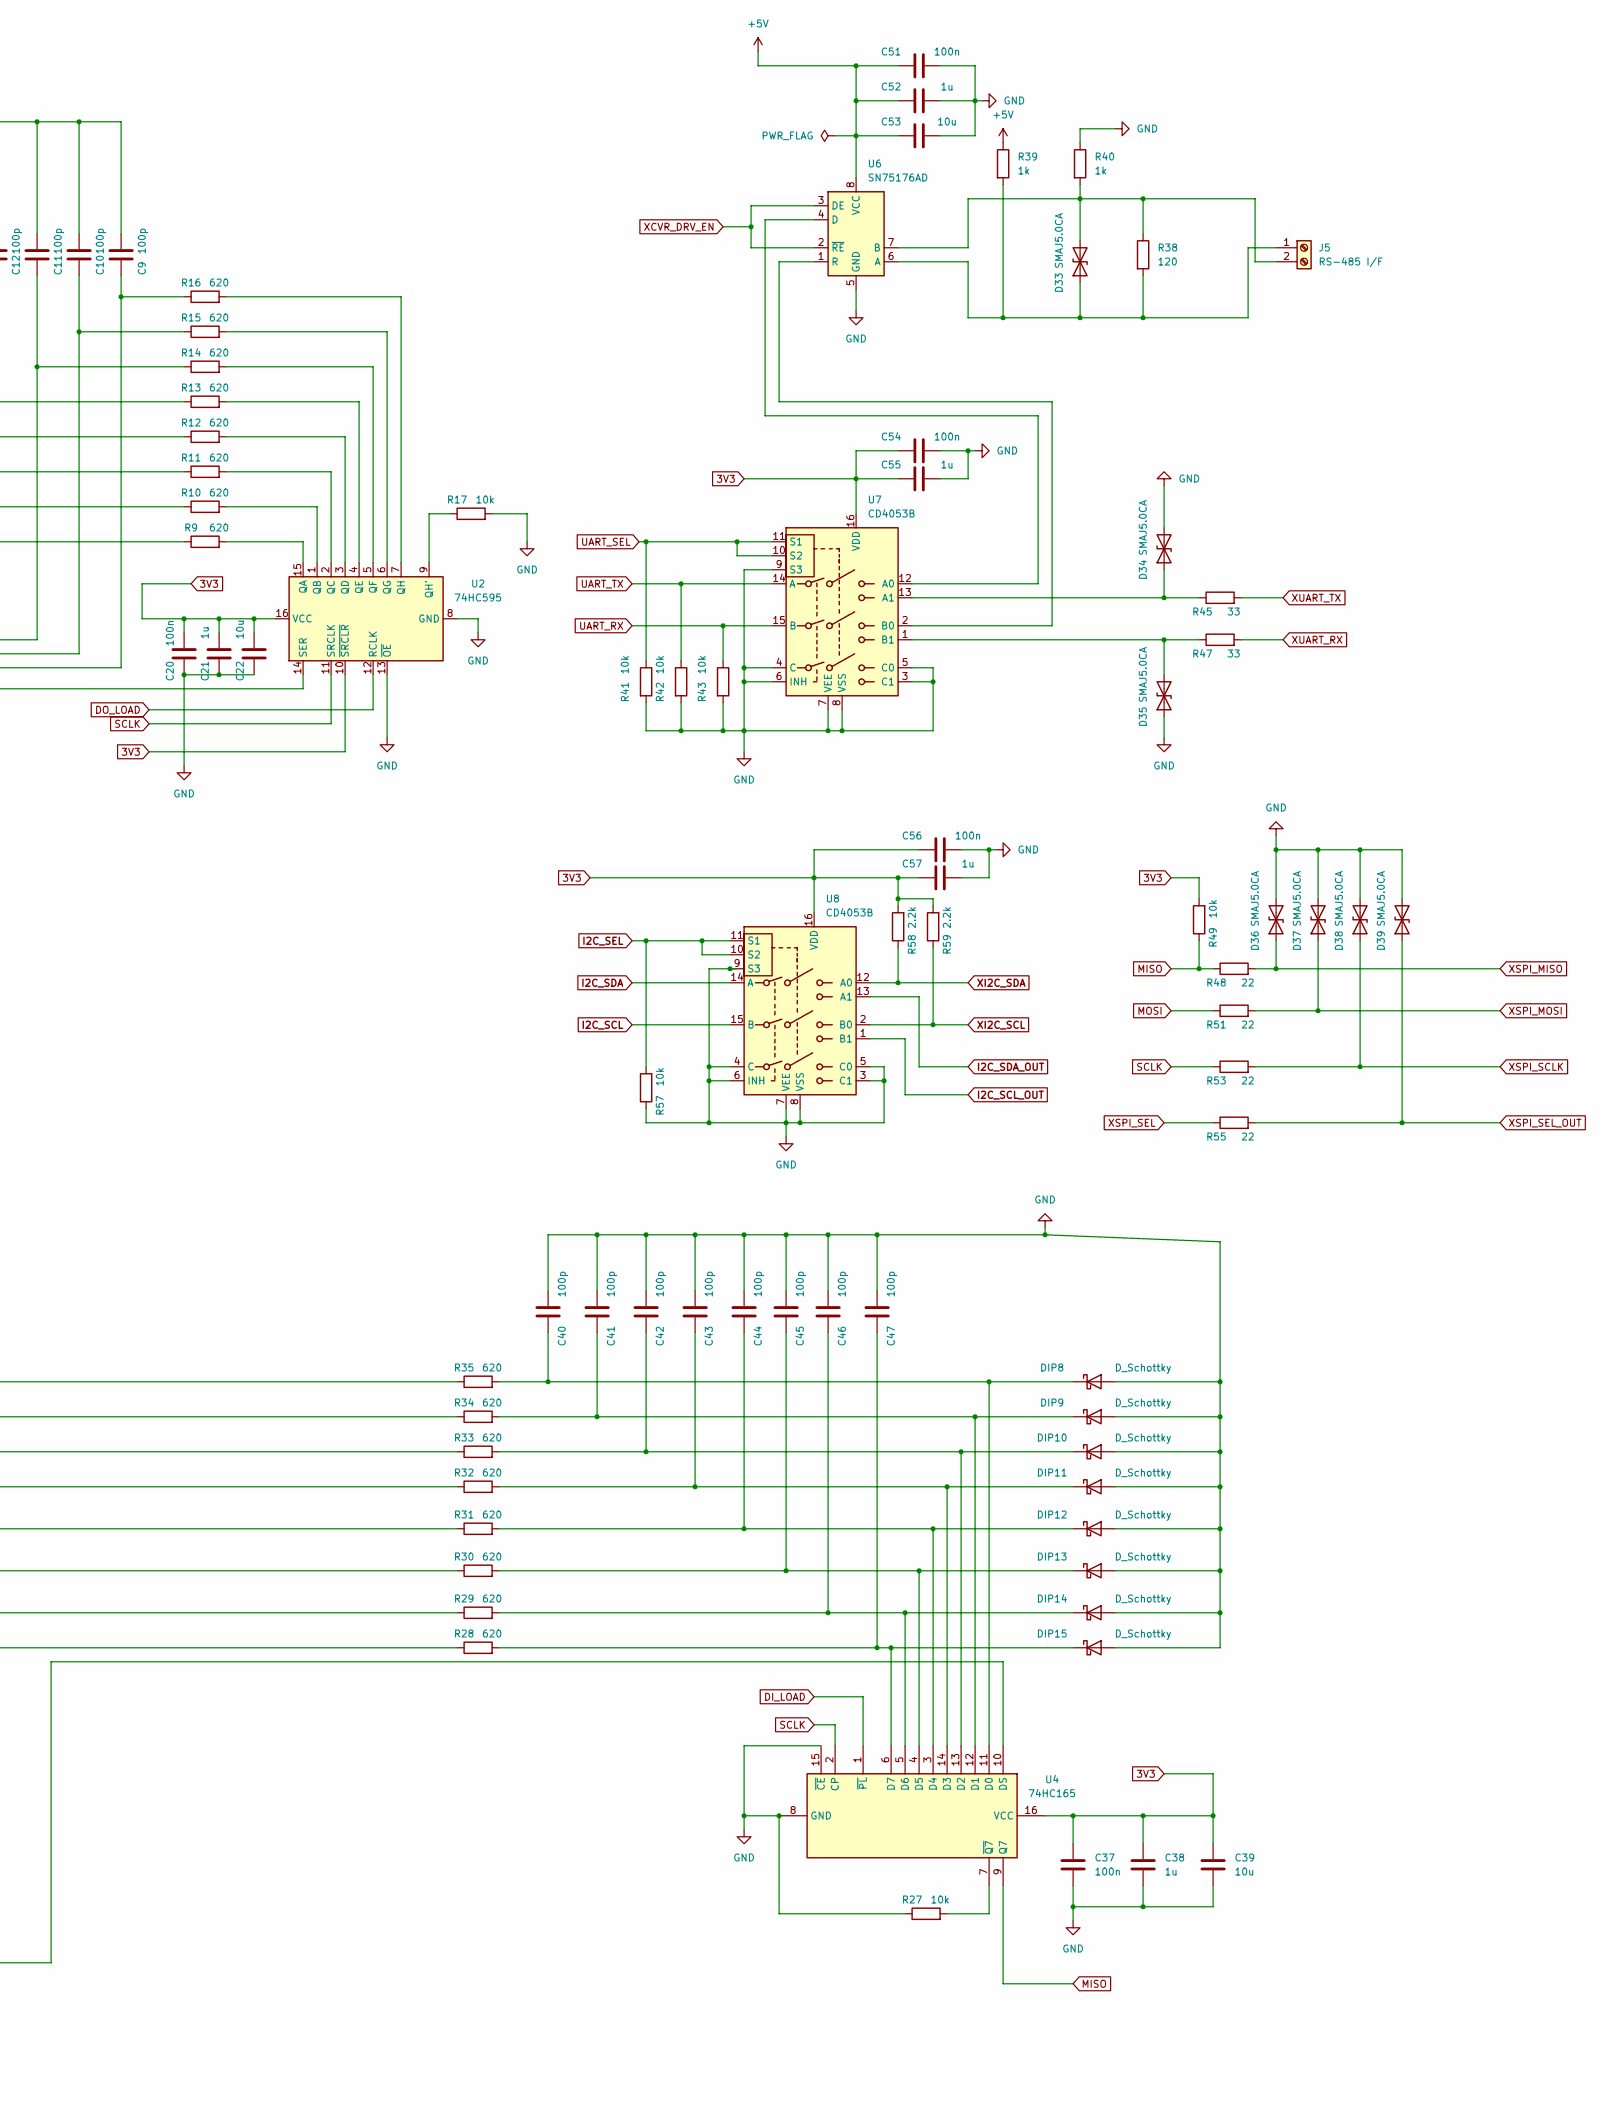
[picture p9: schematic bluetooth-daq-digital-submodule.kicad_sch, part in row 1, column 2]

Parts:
C1, C2, C3, C4, C5, C6, C7, C8, C9, C10, C11, C12, C13, C14, C15, C16, C29, C30, C31, C32, C33, C34, C35, C36, C40, C41, C42, C43, C44, C45, C46, C47: 100p; C_0805_2012Metric_Pad1.18x1.45mm_HandSolder
C17, C20, C23, C37, C48, C51, C54, C56: 100n; C_0805_2012Metric_Pad1.18x1.45mm_HandSolder
C18, C21, C24, C38, C49, C52, C55, C57: 1u; C_0805_2012Metric_Pad1.18x1.45mm_HandSolder
C19, C22, C25, C39, C50, C53: 10u; C_0805_2012Metric_Pad1.18x1.45mm_HandSolder
D33, D34, D35, D36, D37, D38, D39: SMAJ5.0CA; D_SMA_Handsoldering
DIP0, DIP1, DIP2, DIP3, DIP4, DIP5, DIP6, DIP7, DIP8, DIP9, DIP10, DIP11, DIP12, DIP13, DIP14, DIP15: D_Schottky; D_SMA_Handsoldering
J1: MCU I/F; PinHeader_2x08_P2.54mm_Vertical
J2: Digital Inputs; PinHeader_2x08_P2.54mm_Vertical
J3: Digital Outputs; PinHeader_2x08_P2.54mm_Vertical
J4: Communication I/F; PinHeader_2x08_P2.54mm_Vertical
J5: RS-485 I/F; PhoenixContact_MCV_1,5_2-G-5.08_1x02_P5.08mm_Vertical
R1, R2, R3, R4, R5, R6, R7, R8, R9, R10, R11, R12, R13, R14, R15, R16, R18, R19, R20, R21, R22, R23, R24, R25, R28, R29, R30, R31, R32, R33, R34, R35: 620; R_0805_2012Metric_Pad1.20x1.40mm_HandSolder
R17, R26, R27, R41, R42, R43, R49, R57, R200: 10k; R_0805_2012Metric_Pad1.20x1.40mm_HandSolder
R38: 120; R_1206_3216Metric_Pad1.30x1.75mm_HandSolder
R39, R40: 1k; R_1206_3216Metric_Pad1.30x1.75mm_HandSolder
R45, R47: 33; R_0805_2012Metric_Pad1.20x1.40mm_HandSolder
R48, R51, R53, R55: 22; R_0805_2012Metric_Pad1.20x1.40mm_HandSolder
R58, R59: 2.2k; R_0805_2012Metric_Pad1.20x1.40mm_HandSolder
U1, U2: 74HC595; SOIC-16_3.9x9.9mm_P1.27mm
U3, U4: 74HC165; D16
U5: 24LC1025; SOIC8-N_MC_MCH
U6: SN75176AD; SOIC-8_3.9x4.9mm_P1.27mm
U7, U8: CD4053B; D16

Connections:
3V3: C17.1, C18.1, C19.1, C20.1, C21.1, C22.1, C23.1, C24.1, C25.1, C37.1, C38.1, C39.1, C48.1, C49.1, C50.1, C54.1, C55.1, C56.1, C57.1, J1.9, R49.2, R58.2, R59.2, U1.10 (~SRCLR), U1.16 (VCC), U2.10 (~SRCLR), U2.16 (VCC), U3.16 (VCC), U4.16 (VCC), U5.7 (WP), U5.8 (VCC), U7.16 (VDD), U8.16 (VDD)
5V: C51.1, C52.1, C53.1, J4.2, R39.1, U6.8 (VCC)
DIN0: J2.1, R25.1
DIN1: J2.3, R24.1
DIN2: J2.5, R23.1
DIN3: J2.7, R22.1
DIN4: J2.9, R21.1
DIN5: J2.11, R20.1
DIN6: J2.13, R19.1
DIN7: J2.15, R18.1
DIN8: J2.16, R35.1
DIN9: J2.14, R34.1
DIN10: J2.12, R33.1
DIN11: J2.10, R32.1
DIN12: J2.8, R31.1
DIN13: J2.6, R30.1
DIN14: J2.4, R29.1
DIN15: J2.2, R28.1
DI_LOAD: J1.10, U3.1 (~PL), U4.1 (~PL)
DOUT0: C8.2, J3.15, R1.1
DOUT1: C7.2, J3.13, R2.1
DOUT2: C6.2, J3.11, R3.1
DOUT3: C5.2, J3.9, R4.1
DOUT4: C4.2, J3.7, R5.1
DOUT5: C3.2, J3.5, R6.1
DOUT6: C2.2, J3.3, R7.1
DOUT7: C1.2, J3.1, R8.1
DOUT8: C16.2, J3.2, R9.1
DOUT9: C15.2, J3.4, R10.1
DOUT10: C14.2, J3.6, R11.1
DOUT11: C13.2, J3.8, R12.1
DOUT12: C12.2, J3.10, R13.1
DOUT13: C11.2, J3.12, R14.1
DOUT14: C10.2, J3.14, R15.1
DOUT15: C9.2, J3.16, R16.1
DO_LOAD: J1.12, U1.12 (RCLK), U2.12 (RCLK)
GND: C1.1, C2.1, C3.1, C4.1, C5.1, C6.1, C7.1, C8.1, C9.1, C10.1, C11.1, C12.1, C13.1, C14.1, C15.1, C16.1, C17.2, C18.2, C19.2, C20.2, C21.2, C22.2, C23.2, C24.2, C25.2, C29.1, C30.1, C31.1, C32.1, C33.1, C34.1, C35.1, C36.1, C37.2, C38.2, C39.2, C40.1, C41.1, C42.1, C43.1, C44.1, C45.1, C46.1, C47.1, C48.2, C49.2, C50.2, C51.2, C52.2, C53.2, C54.2, C55.2, C56.2, C57.2, D34.2 (A2), D35.1 (A1), D36.2 (A2), D37.2 (A2), D38.2 (A2), D39.2 (A2), DIP0.2 (A), DIP1.2 (A), DIP2.2 (A), DIP3.2 (A), DIP4.2 (A), DIP5.2 (A), DIP6.2 (A), DIP7.2 (A), DIP8.2 (A), DIP9.2 (A), DIP10.2 (A), DIP11.2 (A), DIP12.2 (A), DIP13.2 (A), DIP14.2 (A), DIP15.2 (A), J1.16, J4.8, J4.10, J4.12, J4.14, J4.16, R17.2, R26.1, R27.1, R40.1, R41.2, R42.2, R43.2, R57.1, R200.1, U1.8 (GND), U1.13 (~OE), U2.8 (GND), U2.13 (~OE), U3.8 (GND), U3.10 (DS), U3.15 (~CE), U4.8 (GND), U4.15 (~CE), U5.4 (GND), U6.5 (GND), U7.3 (C1), U7.4 (C), U7.5 (C0), U7.6 (INH), U7.7 (VEE), U7.8 (VSS), U7.9 (S3), U8.3 (C1), U8.4 (C), U8.5 (C0), U8.6 (INH), U8.7 (VEE), U8.8 (VSS), U8.9 (S3)
I2C_SCL: J1.8, U8.15 (B)
I2C_SCL_OUT: J4.6, U8.1 (B1)
I2C_SDA: J1.6, U8.14 (A)
I2C_SDA_OUT: J4.4, U8.13 (A1)
I2C_SEL: J1.4, R57.2, U8.10 (S2), U8.11 (S1)
MISO: J1.3, R48.1, R49.1, U4.9 (Q7), U5.2 (A1)
MOSI: J1.1, R51.1, U1.14 (SER), U5.5 (SDA)
unnamed: C29.2, DIP7.1 (K), R18.2, U3.6 (D7)
unnamed: C30.2, DIP6.1 (K), R19.2, U3.5 (D6)
unnamed: C31.2, DIP5.1 (K), R20.2, U3.4 (D5)
unnamed: C32.2, DIP4.1 (K), R21.2, U3.3 (D4)
unnamed: C33.2, DIP3.1 (K), R22.2, U3.14 (D3)
unnamed: C34.2, DIP2.1 (K), R23.2, U3.13 (D2)
unnamed: C35.2, DIP1.1 (K), R24.2, U3.12 (D1)
unnamed: C36.2, DIP0.1 (K), R25.2, U3.11 (D0)
unnamed: C40.2, DIP8.1 (K), R35.2, U4.11 (D0)
unnamed: C41.2, DIP9.1 (K), R34.2, U4.12 (D1)
unnamed: C42.2, DIP10.1 (K), R33.2, U4.13 (D2)
unnamed: C43.2, DIP11.1 (K), R32.2, U4.14 (D3)
unnamed: C44.2, DIP12.1 (K), R31.2, U4.3 (D4)
unnamed: C45.2, DIP13.1 (K), R30.2, U4.4 (D5)
unnamed: C46.2, DIP14.1 (K), R29.2, U4.5 (D6)
unnamed: C47.2, DIP15.1 (K), R28.2, U4.6 (D7)
unnamed: D33.1 (A1), J5.1, R38.2, R39.2, U6.6 (A)
unnamed: D33.2 (A2), J5.2, R38.1, R40.2, U6.7 (B)
unnamed: D34.1 (A1), R45.1, U7.13 (A1)
unnamed: D35.2 (A2), R47.1, U7.1 (B1)
unnamed: R1.2, U1.15 (QA)
unnamed: R2.2, U1.1 (QB)
unnamed: R3.2, U1.2 (QC)
unnamed: R4.2, U1.3 (QD)
unnamed: R5.2, U1.4 (QE)
unnamed: R6.2, U1.5 (QF)
unnamed: R7.2, U1.6 (QG)
unnamed: R8.2, U1.7 (QH)
unnamed: R9.2, U2.15 (QA)
unnamed: R10.2, U2.1 (QB)
unnamed: R11.2, U2.2 (QC)
unnamed: R12.2, U2.3 (QD)
unnamed: R13.2, U2.4 (QE)
unnamed: R14.2, U2.5 (QF)
unnamed: R15.2, U2.6 (QG)
unnamed: R16.2, U2.7 (QH)
unnamed: R17.1, U2.9 (QH')
unnamed: R26.2, U3.7 (~Q7)
unnamed: R27.2, U4.7 (~Q7)
unnamed: R200.2, U5.3 (A2)
unnamed: U1.9 (QH'), U2.14 (SER)
unnamed: U3.9 (Q7), U4.10 (DS)
unnamed: U6.1 (R), U7.2 (B0)
unnamed: U6.4 (D), U7.12 (A0)
SCLK: J1.5, R53.1, U1.11 (SRCLK), U2.11 (SRCLK), U3.2 (CP), U4.2 (CP), U5.6 (SCL)
UART_RX: J1.15, R43.1, U7.15 (B)
UART_SEL: J1.11, R41.1, U7.10 (S2), U7.11 (S1)
UART_TX: J1.13, R42.1, U7.14 (A)
XCVR_DRV_EN: J1.2, U6.2 (~RE), U6.3 (DE)
XI2C_SCL: J4.15, R59.1, U8.2 (B0)
XI2C_SDA: J4.13, R58.1, U8.12 (A0)
XRAM_SEL: J1.7, U5.1 (A0)
XSPI_MISO: D36.1 (A1), J4.3, R48.2
XSPI_MOSI: D37.1 (A1), J4.5, R51.2
XSPI_SCLK: D38.1 (A1), J4.7, R53.2
XSPI_SEL: J1.14, R55.1
XSPI_SEL_OUT: D39.1 (A1), J4.1, R55.2
XUART_RX: J4.11, R47.2
XUART_TX: J4.9, R45.2

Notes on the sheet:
EXTERNAL SRAM
HEADER PINS
DIGITAL INPUTS
DIGITAL OUTPUTS
Used as placeholder for 23LCV1024

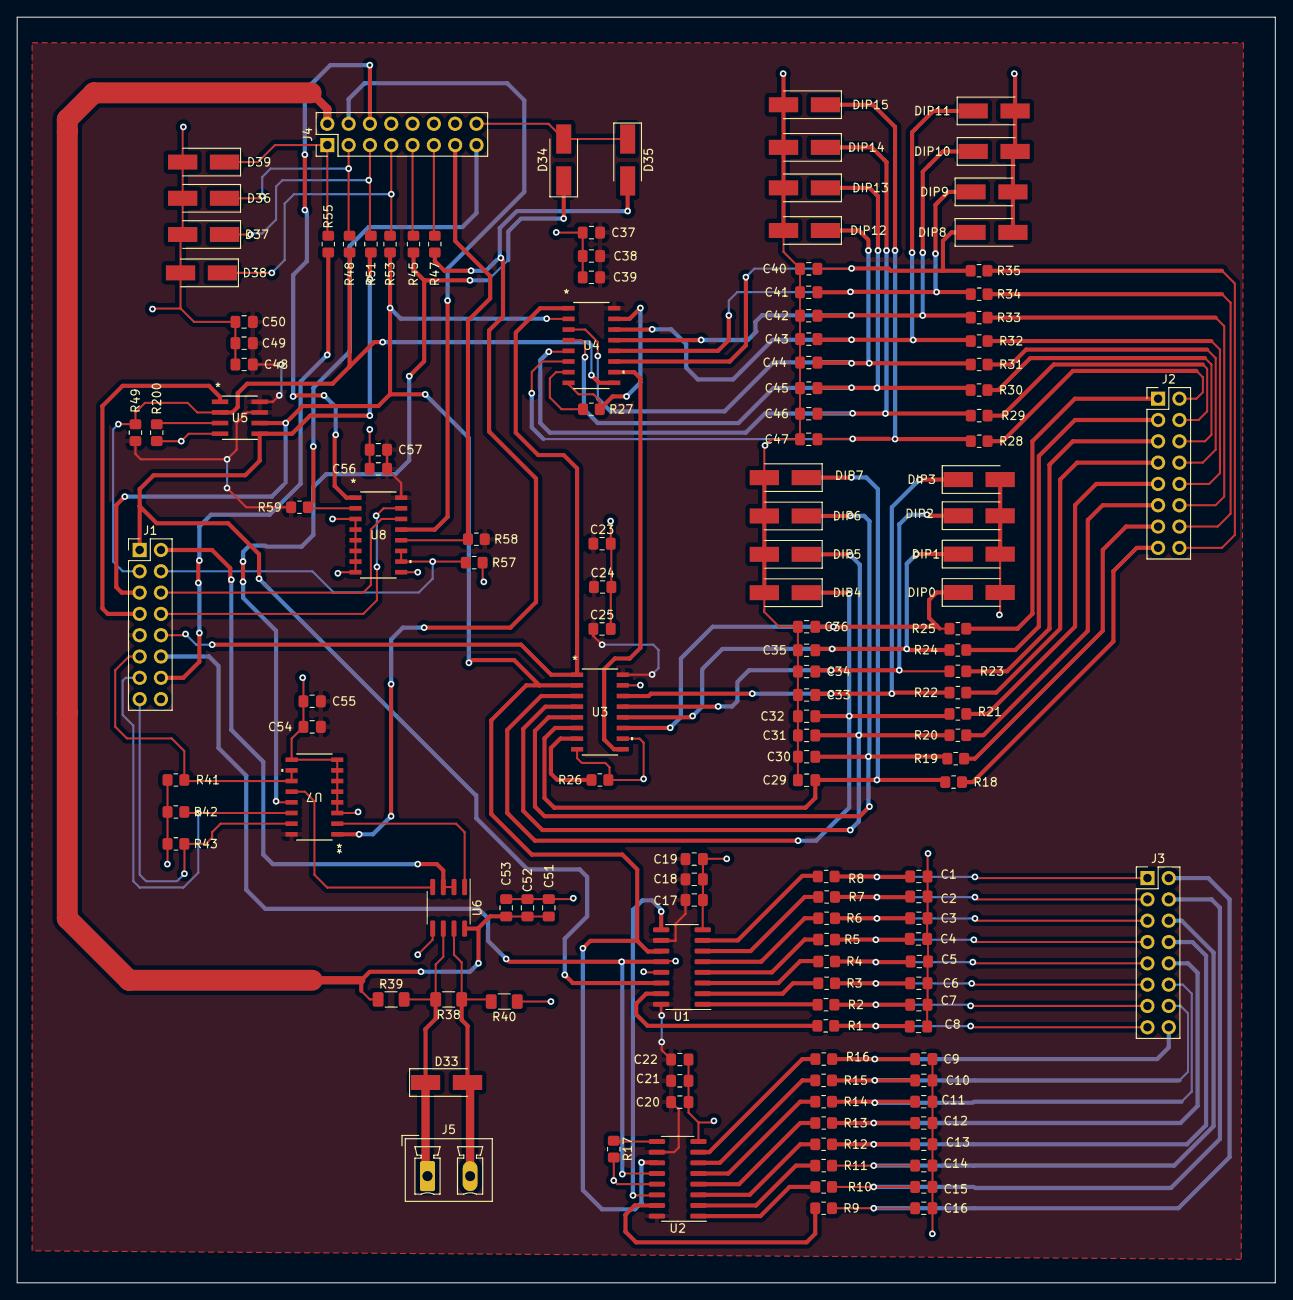
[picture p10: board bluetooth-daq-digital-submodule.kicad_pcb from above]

Board: 2 copper layers, 150.0 x 150.9 mm, 142 parts (0 on the bottom side), 103 nets.

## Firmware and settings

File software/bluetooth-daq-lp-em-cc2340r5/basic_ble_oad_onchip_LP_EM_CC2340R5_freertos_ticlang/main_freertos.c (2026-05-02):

/******************************************************************************

 @file  main_freertos.c

 @brief main entry of the BLE stack sample application.

 Group: WCS, BTS
 Target Device: cc23xx

 ******************************************************************************
 
 Copyright (c) 2013-2025, Texas Instruments Incorporated
 All rights reserved.

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
 *  Neither the name of Texas Instruments Incorporated nor the names of
    its contributors may be used to endorse or promote products derived
    from this software without specific prior written permission.


 THIS SOFTWARE IS PROVIDED BY THE COPYRIGHT HOLDERS AND CONTRIBUTORS "AS IS"
 AND ANY EXPRESS OR IMPLIED WARRANTIES, INCLUDING, BUT NOT LIMITED TO,
 THE IMPLIED WARRANTIES OF MERCHANTABILITY AND FITNESS FOR A PARTICULAR
 PURPOSE ARE DISCLAIMED. IN NO EVENT SHALL THE COPYRIGHT OWNER OR
 CONTRIBUTORS BE LIABLE FOR ANY DIRECT, INDIRECT, INCIDENTAL, SPECIAL,
 EXEMPLARY, OR CONSEQUENTIAL DAMAGES (INCLUDING, BUT NOT LIMITED TO,
 PROCUREMENT OF SUBSTITUTE GOODS OR SERVICES; LOSS OF USE, DATA, OR PROFITS;
 OR BUSINESS INTERRUPTION) HOWEVER CAUSED AND ON ANY THEORY OF LIABILITY,
 WHETHER IN CONTRACT, STRICT LIABILITY, OR TORT (INCLUDING NEGLIGENCE OR
 OTHERWISE) ARISING IN ANY WAY OUT OF THE USE OF THIS SOFTWARE,
 EVEN IF ADVISED OF THE POSSIBILITY OF SUCH DAMAGE.

 ******************************************************************************
 
 
 *****************************************************************************/

/*******************************************************************************
 * INCLUDES
 */

/* RTOS header files */
#include <FreeRTOS.h>
#include <stdint.h>
#include <task.h>
#include <pthread.h>
#include <semaphore.h>

#include <ti/posix/ticlang/sys/types.h>

extern int pthread_mutex_init(pthread_mutex_t *mutex, const pthread_mutexattr_t *attr);
extern int pthread_mutex_lock(pthread_mutex_t *mutex);
extern int pthread_mutex_unlock(pthread_mutex_t *mutex);


#ifdef __ICCARM__
    #include <DLib_Threads.h>
#endif
#include <ti/drivers/Power.h>
#include <ti/devices/DeviceFamily.h>
#include <ti/drivers/timer/LGPTimerLPF3.h>

#include "ti/ble/stack_util/icall/app/icall.h"
#include "ti/ble/stack_util/health_toolkit/assert.h"
#include "ti/ble/stack_util/bcomdef.h"

#ifndef USE_DEFAULT_USER_CFG
#include "ti/ble/app_util/config/ble_user_config.h"
#include <ti/devices/cc23x0r5/driverlib/hapi.h>

#include <ti/drivers/ADC.h>

// BLE user defined configuration
icall_userCfg_t user0Cfg = BLE_USER_CFG;
#endif // USE_DEFAULT_USER_CFG



/*******************************************************************************
 * MACROS
 */

/*******************************************************************************
 * CONSTANTS
 */

/*******************************************************************************
 * TYPEDEFS
 */

/*******************************************************************************
 * LOCAL VARIABLES
 */

/*******************************************************************************
 * GLOBAL VARIABLES
 */

/*******************************************************************************
 * EXTERNS
 */
extern void appMain(void);
extern void AssertHandler(uint8 assertCause, uint8 assertSubcause);

/*******************************************************************************
 * @fn          Main
 *
 * @brief       Application Main
 *
 * input parameters
 *
 * @param       None.
 *
 * output parameters
 *
 * @param       None.
 *
 * @return      None.
 */

LGPTimerLPF3_Handle timerHandle;
LGPTimerLPF3_Params timerParams;
sem_t timerSem;
int timerIsrCount;

static void timer_callback(LGPTimerLPF3_Handle handle, LGPTimerLPF3_IntMask interruptMask)
{
    sem_post(&timerSem);
}

void timer_init()
{
    uint32_t counterTarget;
    int ret;

    LGPTimerLPF3_Params_init(&timerParams);
    timerParams.hwiCallbackFxn = timer_callback;

    timerHandle = LGPTimerLPF3_open(CONFIG_LGPTIMER_0, &timerParams);

    if(timerHandle == NULL)
    {
        __asm volatile("bkpt 0");
    }

    // Set counter target
    counterTarget = 480000 - 1;  // 10 ms with a system clock of 48 MHz
    LGPTimerLPF3_setInitialCounterTarget(timerHandle, counterTarget, true);

    // Enable counter target interrupt
    LGPTimerLPF3_enableInterrupt(timerHandle, LGPTimerLPF3_INT_TGT);

    ret = sem_init(&timerSem, 0, 1);

    // Start counter in count-up-periodic mode
    LGPTimerLPF3_start(timerHandle, LGPTimerLPF3_CTL_MODE_UP_PER);    
}


ADC_Handle adc1Handle;
ADC_Handle adc2Handle;

ADC_Params adcParams;

void hsadc_init()
{
  ADC_init();

  ADC_Params_init(&adcParams);

  adc1Handle = ADC_open(CONFIG_ADC_0, &adcParams);
  adc2Handle = ADC_open(CONFIG_ADC_1, &adcParams);    
}


LGPTimerLPF3_Handle hsadcTimerHandle;

#define HSADC_MAX_SAMPLE_COUNT  512

volatile int hsadc_currentSampleCount = 0;
volatile int hsadc_targetSampleCount = 0;
volatile int hsadc_currentChannel = 0;
volatile int hsadc_dualChannelMode = 0;
volatile int hsadc_singleModeChannel = 0;

volatile uint16_t hsadc_channel1Samples[HSADC_MAX_SAMPLE_COUNT];
volatile uint16_t hsadc_channel2Samples[HSADC_MAX_SAMPLE_COUNT];

static void hsadctimer_callback(LGPTimerLPF3_Handle handle, LGPTimerLPF3_IntMask interruptMask)
{
    if( hsadc_dualChannelMode == 0 )
    {
        ADC_convert(adc1Handle, &hsadc_channel1Samples[hsadc_currentSampleCount]);

        hsadc_currentSampleCount++;
    }
    else 
    {
        if( hsadc_currentChannel == 0 )
        {
            ADC_convert(adc1Handle, &hsadc_channel1Samples[hsadc_currentSampleCount]);
            hsadc_currentChannel = 1;
        }
        else
        {
            ADC_convert(adc2Handle, &hsadc_channel2Samples[hsadc_currentSampleCount]);
            hsadc_currentChannel = 0;
            hsadc_currentSampleCount++;
        }
    }

    if( hsadc_currentSampleCount == hsadc_targetSampleCount )
    {
        LGPTimerLPF3_stop(hsadcTimerHandle);
    }
}

void hsadcTimer_init()
{
    uint32_t counterTarget;
    int ret;

    LGPTimerLPF3_Params_init(&timerParams);
    timerParams.hwiCallbackFxn = hsadctimer_callback;

    hsadcTimerHandle = LGPTimerLPF3_open(CONFIG_LGPTIMER_1, &timerParams);

    if(hsadcTimerHandle == NULL)
    {
        __asm volatile("bkpt 0");
    }

    // Set counter target
    counterTarget = 960 - 1;  // 50 us with a system clock of 48 MHz
    LGPTimerLPF3_setInitialCounterTarget(hsadcTimerHandle, counterTarget, true);
}

void hsadc_start(int sample_count, int mode)
{
    hsadc_targetSampleCount = sample_count;
    hsadc_dualChannelMode = mode;
    hsadc_currentSampleCount = 0;

    // Enable counter target interrupt
    LGPTimerLPF3_enableInterrupt(hsadcTimerHandle, LGPTimerLPF3_INT_TGT);

    // Start counter in count-up-periodic mode
    LGPTimerLPF3_start(hsadcTimerHandle, LGPTimerLPF3_CTL_MODE_UP_PER);    
}

int hsadc_convertToMillivolts(int raw)
{
    int temp;

    temp = 114*raw -89695;

    return (int)temp;
}

int hsadc_readSample(int channel, int index)
{
    if( channel == 0 )
    {
        return ( hsadc_convertToMillivolts(hsadc_channel1Samples[index]) );
    }

    return hsadc_channel2Samples[index];
}

bool hsadc_isPending()
{
    return (hsadc_currentSampleCount < hsadc_targetSampleCount );
}

extern void sscpRS485Process();
extern void sscpBleProcess();

void* sscpProcessingTask(void* args)
{
    while(1) {
        sscpRS485Process();
        sscpBleProcess();
        usleep(1000);
    }
}

extern void analogIsrSection();

void* isrTask(void* args)
{
    while(1)
    {
        sem_wait(&timerSem);
        analogIsrSection();
    }
}

pthread_mutex_t spiMutex;
pthread_mutex_t i2cMutex;

int main()
{
  /* Register Application callback to trap asserts raised in the Stack */
  halAssertCback = AssertHandler;
  RegisterAssertCback(AssertHandler);

  Board_init();

  hsadc_init();

  /* Update User Configuration of the stack */
  user0Cfg.appServiceInfo->timerTickPeriod = ICall_getTickPeriod();
  user0Cfg.appServiceInfo->timerMaxMillisecond  = ICall_getMaxMSecs();

  /* Initialize all applications tasks */
  appMain();

  //hsadc_init();
  hsadcTimer_init();
  timer_init();


 HapiWaitUs(10000);

  extern void digitalSubmodule_init();
  digitalSubmodule_init();

  pthread_mutex_init(&i2cMutex, NULL);
  pthread_mutex_init(&spiMutex, NULL);

  pthread_t thread;
  pthread_attr_t attrs;
  struct sched_param priParam;
  int retc;

  /* Initialize the attributes structure with default values */
  pthread_attr_init(&attrs);

  /* Set priority, detach state, and stack size attributes */
  priParam.sched_priority = 3;
  retc                    = pthread_attr_setschedparam(&attrs, &priParam);
  retc |= pthread_attr_setdetachstate(&attrs, PTHREAD_CREATE_DETACHED);
  retc |= pthread_attr_setstacksize(&attrs, 2048);
  if (retc != 0)
  {
    /* failed to set attributes */
    while (1) {}
  }

  retc = pthread_create(&thread, &attrs, sscpProcessingTask, NULL);

  if (retc != 0)
  {
    /* pthread_create() failed */
    while (1) {}
  }

  /* Initialize the attributes structure with default values */
  pthread_attr_init(&attrs);

  /* Set priority, detach state, and stack size attributes */
  priParam.sched_priority = 1;
  retc                    = pthread_attr_setschedparam(&attrs, &priParam);
  retc |= pthread_attr_setdetachstate(&attrs, PTHREAD_CREATE_DETACHED);
  retc |= pthread_attr_setstacksize(&attrs, 1024);
  if (retc != 0)
  {
    /* failed to set attributes */
    while (1) {}
  }

  retc = pthread_create(&thread, &attrs, isrTask, NULL);

  if (retc != 0)
  {
    /* pthread_create() failed */
    while (1) {}
  }


  /* Start the FreeRTOS scheduler */
  vTaskStartScheduler();

  return 0;

}

//*****************************************************************************
//
//! \brief Application defined stack overflow hook
//!
//! \param  none
//!
//! \return none
//!
//*****************************************************************************
void vApplicationStackOverflowHook(TaskHandle_t pxTask, char *pcTaskName)
{
    //Handle FreeRTOS Stack Overflow
    AssertHandler(HAL_ASSERT_CAUSE_STACK_OVERFLOW_ERROR, 0);
}

/*******************************************************************************
 * @fn          AssertHandler
 *
 * @brief       This is the Application's callback handler for asserts raised
 *              in the stack.  When EXT_HAL_ASSERT is defined in the Stack Wrapper
 *              project this function will be called when an assert is raised,
 *              and can be used to observe or trap a violation from expected
 *              behavior.
 *
 *              As an example, for Heap allocation failures the Stack will raise
 *              HAL_ASSERT_CAUSE_OUT_OF_MEMORY as the assertCause and
 *              HAL_ASSERT_SUBCAUSE_NONE as the assertSubcause.  An application
 *              developer could trap any malloc failure on the stack by calling
 *              HAL_ASSERT_SPINLOCK under the matching case.
 *
 *              An application developer is encouraged to extend this function
 *              for use by their own application.  To do this, add assert.c
 *              to your project workspace, the path to assert.h (this can
 *              be found on the stack side). Asserts are raised by including
 *              assert.h and using macro HAL_ASSERT(cause) to raise an
 *              assert with argument assertCause.  the assertSubcause may be
 *              optionally set by macro HAL_ASSERT_SET_SUBCAUSE(subCause) prior
 *              to asserting the cause it describes. More information is
 *              available in assert.h.
 *
 * input parameters
 *
 * @param       assertCause    - Assert cause as defined in assert.h.
 * @param       assertSubcause - Optional assert subcause (see assert.h).
 *
 * output parameters
 *
 * @param       None.
 *
 * @return      None.
 */
void AssertHandler(uint8_t assertCause, uint8_t assertSubcause)
{
    // check the assert cause
    switch(assertCause)
    {
        case HAL_ASSERT_CAUSE_OUT_OF_MEMORY:
        {
            // ERROR: OUT OF MEMORY
            HAL_ASSERT_SPINLOCK;
            break;
        }

        case HAL_ASSERT_CAUSE_INTERNAL_ERROR:
        {
            // check the subcause
            if(assertSubcause == HAL_ASSERT_SUBCAUSE_FW_INERNAL_ERROR)
            {
                // ERROR: INTERNAL FW ERROR
                HAL_ASSERT_SPINLOCK;
            }
            else
            {
                // ERROR: INTERNAL ERROR
                HAL_ASSERT_SPINLOCK;
            }
            break;
        }

        case HAL_ASSERT_CAUSE_ICALL_ABORT:
        {
            HAL_ASSERT_SPINLOCK;
            break;
        }

        case HAL_ASSERT_CAUSE_ICALL_TIMEOUT:
        {
            HAL_ASSERT_SPINLOCK;
            break;
        }

        case HAL_ASSERT_CAUSE_WRONG_API_CALL:
        {
            HAL_ASSERT_SPINLOCK;
            break;
        }

        case HAL_ASSERT_CAUSE_STACK_OVERFLOW_ERROR:
        {
            HAL_ASSERT_SPINLOCK;
            break;
        }

        case HAL_ASSERT_CAUSE_LL_INIT_RNG_NOISE_FAILURE:
        {
            /*
             * Device must be reset to recover from this case.
             *
             * The HAL_ASSERT_SPINLOCK with is replacable with custom handling,
             * at the end of which Power_reset(); MUST be called.
             *
             * BLE5-stack functionality will be compromised when LL_initRNGNoise
             * fails.
             */
            HAL_ASSERT_SPINLOCK;
            break;
        }

        default:
        {
            HAL_ASSERT_SPINLOCK;
            break;
        }
    }

    return;
}

/*******************************************************************************
 */

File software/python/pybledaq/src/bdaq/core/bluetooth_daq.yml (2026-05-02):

# Each device requires a seperate YAML file.
# This ensures modularity with respect to the application.
# Each connection to a device requires a seperate YAML file.

defconfig:
  
  # Device name.
  # Required for identifying the device with using BLE.

  name: "bluetooth_daq"

  # Common configuration settings.
  device_number: 0

  # Serial interface COM port.
  serial_port: "COM13"

  # Serial baud rate.
  serial_baud_rate: 115200

  # Socket base port number.
  base_port: 3000

  # Device serial number.
  # Required for BLE mode. Each device must store this serial number
  # in its non-volatile memory.
  device_serial_number: 0000000001

  # Interface communication timeout in milli-seconds.
  interface_timeout_ms:  15000

### Device register description.

regs:
  reg_0:
    number: 0
    name: "GPIO_WRITE"
    comment: "GPIO write register."

    parameter_0:
      number: 0
      name: "GPIO_write_value"
      startbit: 0
      bitlength: 16
      type: "uint"
      min: 0
      max: 65535
    
    parameter_1:
      number: 1
      name: "GPIO_write_value_reserved"
      startbit: 16
      bitlength: 16
      type: "uint"
      min: 0
      max: 65535

  reg_1:
    number: 1
    name: "GPIO_TOGGLE"
    comment: "GPIO Toggle Register."

    parameter_0:
      number: 0
      name: "GPIO_toggle_value"
      startbit: 0
      bitlength: 16
      type: "uint"
      min: 0
      max: 65535
    
    parameter_1:
      number: 1
      name: "GPIO_toggle_value_reserved"
      startbit: 16
      bitlength: 16
      type: "uint"
      min: 0
      max: 65535

  reg_2:
    number: 2
    name: "GPIO_READ"
    comment: "GPIO Read Register."

    parameter_0:
      number: 0
      name: "GPIO_read_value"
      startbit: 0
      bitlength: 16
      type: "uint"
      min: 0
      max: 65535
    
    parameter_1:
      number: 1
      name: "GPIO_read_value_reserved"
      startbit: 16
      bitlength: 16
      type: "uint"
      min: 0
      max: 65535

  reg_3:
    number: 3
    name: "GPIO_PINCTRL"
    comment: "GPIO Pin Control Register."

    parameter_0:
      number: 0
      name: "GPIO_PINCTRL_input_select"
      startbit: 0
      bitlength: 1
      type: "uint"
      min: 0
      max: 1
    
    parameter_1:
      number: 1
      name: "GPIO_PINCTRL_pin_index"
      startbit: 1
      bitlength: 4
      type: "uint"
      min: 0
      max: 15

    parameter_2:
      number: 2
      name: "GPIO_PINCTRL_read"
      startbit: 5
      bitlength: 1
      type: "uint"
      min: 0
      max: 1

    parameter_3:
      number: 3
      name: "GPIO_PINCTRL_write"
      startbit: 6
      bitlength: 1
      type: "uint"
      min: 0
      max: 1

    parameter_4:
      number: 4
      name: "GPIO_PINCTRL_toggle"
      startbit: 7
      bitlength: 1
      type: "uint"
      min: 0
      max: 1

    parameter_5:
      number: 5
      name: "GPIO_PINCTRL_value"
      startbit: 8
      bitlength: 1
      type: "uint"
      min: 0
      max: 1

    parameter_6:
      number: 6
      name: "GPIO_PINCTRL_reserved"
      startbit: 9
      bitlength: 23
      type: "uint"
      min: 0
      max: 1

  reg_4:
    number: 4
    name: "SPI_CONTROL"
    comment: "SPI control register."

    parameter_0:
      number: 0
      name: "SPI_CONTROL_bit_rate"
      startbit: 0
      bitlength: 11
      type: "uint"
      min: 0
      max: 400

    parameter_1:
      number: 1
      name: "SPI_CONTROL_frame_format"
      startbit: 11
      bitlength: 2
      type: "uint"
      min: 0
      max: 3

    parameter_2:
      number: 2
      name: "SPI_CONTROL_transfer_size"
      startbit: 13
      bitlength: 8
      type: "uint"
      min: 0
      max: 255

    parameter_3:
      number: 3
      name: "SPI_CONTROL_cs_polarity"
      startbit: 21
      bitlength: 1
      type: "uint"
      min: 0
      max: 1

    parameter_4:
      number: 4
      name: "SPI_CONTROL_transfer"
      startbit: 22
      bitlength: 1
      type: "uint"
      min: 0
      max: 1

    parameter_5:
      number: 5
      name: "SPI_CONTROL_status"
      startbit: 23
      bitlength: 3
      type: "uint"
      min: 0
      max: 3

    parameter_6:
      number: 6
      name: "SPI_CONTROL_reserved"
      startbit: 26
      bitlength: 6
      type: "uint"
      min: 0
      max: 3

  reg_5:
    number: 5
    name: "SPI_READ_DATA"
    comment: "SPI read data register."

    parameter_0:
      number: 0
      name: "SPI_READ_DATA_index"
      startbit: 0
      bitlength: 8
      type: "uint"
      min: 0
      max: 255

    parameter_1:
      number: 1
      name: "SPI_READ_DATA_byte"
      startbit: 8
      bitlength: 8
      type: "uint"
      min: 0
      max: 255

  reg_6:
    number: 6
    name: "SPI_WRITE_DATA"
    comment: "SPI write data register."

    parameter_0:
      number: 0
      name: "SPI_WRITE_DATA_index"
      startbit: 0
      bitlength: 8
      type: "uint"
      min: 0
      max: 255
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

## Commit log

2026-02-03 docs: Added hardware block diagram for low voltage analog inputs and HV voltage and current inputs.
2026-02-07 Added analog output section block diagram and power supply chain block diagrams
2026-02-07 Added initial schematics for digital submodule
    [bluetooth-daq-digital-submodule.kicad_pcb, bluetooth-daq-digital-submodule.kicad_sch]
2026-02-07 Addressed errors raised by KiCAD for digital sub-module.
    [bluetooth-daq-digital-submodule.kicad_sch]
2026-02-08 Added footprints for components in digital_submodule
    [bluetooth-daq-digital-submodule.kicad_pcb, bluetooth-daq-digital-submodule.kicad_sch]
2026-02-08 Arranged components in PCB view according their functionality
    [bluetooth-daq-digital-submodule.kicad_pcb, bluetooth-daq-digital-submodule.kicad_sch]
2026-02-09 Decided on component arangement for digital input and digital output sections of the digital submodule.
    [bluetooth-daq-digital-submodule.kicad_pcb, bluetooth-daq-digital-submodule.kicad_sch]
2026-02-09 Decided on initial component placement for digital submodule.
    [bluetooth-daq-digital-submodule.kicad_pcb, bluetooth-daq-digital-submodule.kicad_sch]
2026-02-09 Performed initial routing for digital submodule
    [bluetooth-daq-digital-submodule.kicad_pcb, bluetooth-daq-digital-submodule.kicad_sch]
2026-02-10 Routed digital output 1 of digital submodule
    [bluetooth-daq-digital-submodule.kicad_pcb, bluetooth-daq-digital-submodule.kicad_sch]
2026-02-11 Performed routing for interface section for digital submodule.
    [bluetooth-daq-digital-submodule.kicad_pcb, bluetooth-daq-digital-submodule.kicad_sch]
2026-02-11 Completed initial routing of digital sub module
    [bluetooth-daq-digital-submodule.kicad_pcb]
2026-02-12 Performed first successful initial PCB routing
    [bluetooth-daq-digital-submodule.kicad_pcb, bluetooth-daq-digital-submodule.kicad_sch]
2026-02-12 Resolved PCB design errors
    [bluetooth-daq-digital-submodule.kicad_pcb]
2026-02-15 Added Gerber files
    [bluetooth-daq-digital-submodule-B_Cu.gbr, bluetooth-daq-digital-submodule-B_Mask.gbr, bluetooth-daq-digital-submodule-B_Paste.gbr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]
2026-03-08 Added schematics and BoM
    [BoM_digital_submodule.xlsx]
2026-03-09 Added simulations for LV & HV voltage sensing AFE
2026-03-22 Added analog submodule design
    [analog_submodule.kicad_pcb, analog_submodule.kicad_sch]
2026-03-22 Added PCB terminal labels
2026-03-25 Added code for PCB validation for XUART & XSPI
2026-03-25 Added i2c & RS485 interface test codes
2026-03-29 Completed PCB design for analog submodule
    [analog_submodule.kicad_pcb, analog_submodule.kicad_sch]
2026-03-30 Cleaned up resource management strategy
    [analog_submodule-B_Cu.gbr, analog_submodule-B_Mask.gbr, analog_submodule-B_Paste.gbr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]
2026-03-31 Added GPIO and SPI control support via SSCP stack
2026-04-01 Added skeleton for UART control via SSCP stack
2026-04-01 Added SSCP stack support for I2C & UART
2026-04-04 Added APIs for I2C and SPI sudmodules in python/README.md
2026-04-05 Added I2C module in Python
2026-04-07 Added tests for SPI, UART, I2C and GPIO Python drivers
